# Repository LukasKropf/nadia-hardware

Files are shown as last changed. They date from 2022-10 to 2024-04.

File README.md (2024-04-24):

# NADIA - Hardware

- 3 galvanisch getrennte RS-232 Schnittstellen, [MAX33250EELC+](https://media.digikey.com/pdf/Data%20Sheets/Maxim%20PDFs/MAX33250E_51E_Rev1_Nov2018.pdf)
- 5 digitale Eingänge
- 5 analoge Eingänge
- 3 galvanisch getrennte Ausgänge (Solid State Relais, [G3VM-61GR2](https://omronfs.omron.com/en_US/ecb/products/pdf/en-g3vm_41gr8_61gr.pdf))
- Galvanisch getrennte PoE Speisung

## Übersicht

``` mermaid
flowchart LR
    A[M12 Ethernet mit PoE] --- B[NADIA]
    B --- C[5 Digitale Eingänge]
    B --- D[5 Analoge Eingänge]
    B --- E[3 RS-232 Schnittstellen]
    B --- F[3 Digitale Ausgänge]    
    G[Optionale Speisung] -.- B
    H[micro-USB] -.- B
    I[micro-SD Karte] --- B
    
```
|NADIA im Gehäuse | NADIA PCB |
|-|-|
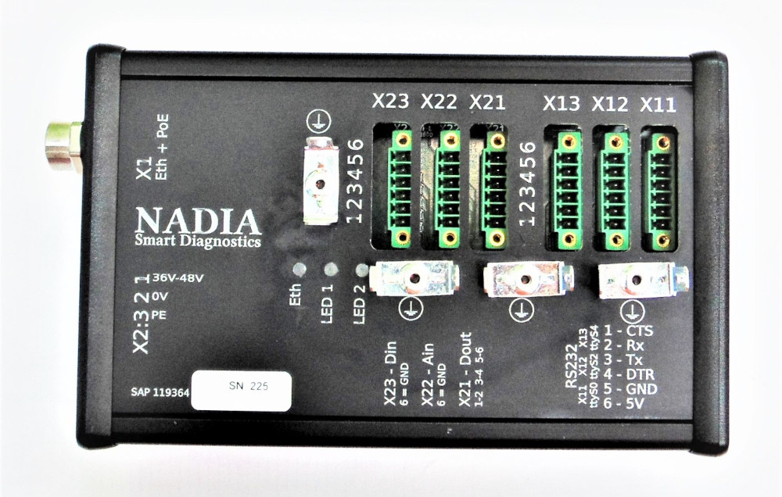
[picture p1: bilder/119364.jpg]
NADIA Foto
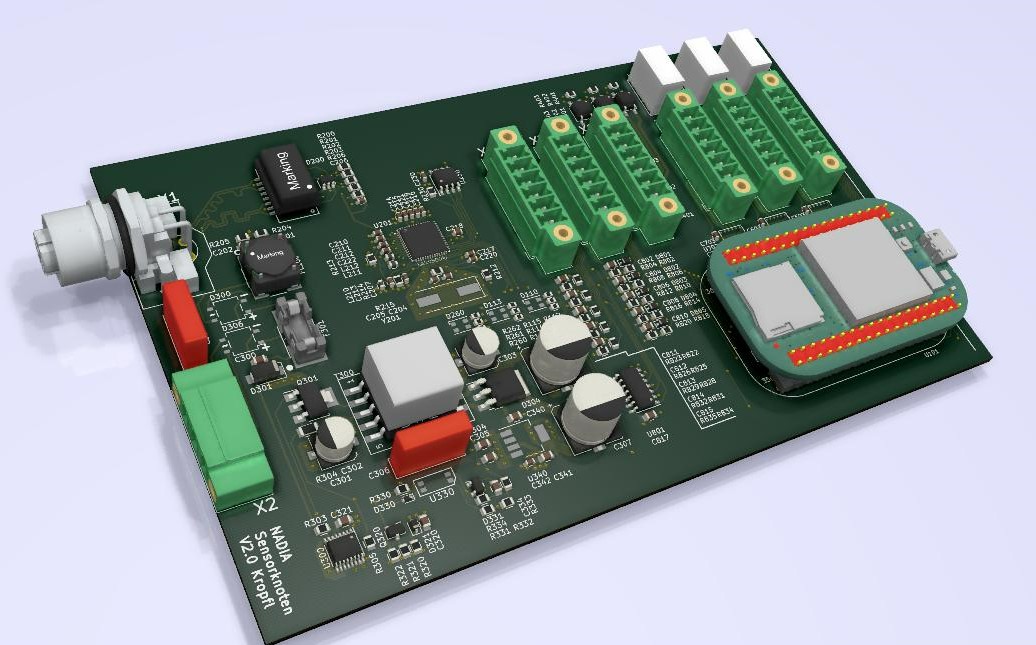
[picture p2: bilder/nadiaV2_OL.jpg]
NADIA PCB
|  ||

## Rechnerplatine

| Wert | Wert | Einheit |
|:---|---|---|
| Rechnerplatine  [Pocketbeagle](https://beagleboard.org/pocket) |  | - |
| RAM |  512 | MB,  DDR3 RAM|
| CPU  [Octavo Systems OSD3358-SM](http://octavosystems.com/octavo_products/osd335x-sm/) |  1 | GHz |
| Speicher |  - | microSD |

## Elektrische Charakteristik

| Wert | Min  | Typisch  | Max | Einheit |
|:---|---|:---:|---|---|
| Speisung Spannung | 36 | 48 | 56 | VDC |
| Speisung Strom | | 50 | 100 | mA |
| Galvanische Trennung Speisung | | | 1.5 | kV |
| **Digitaler Eingang** |
| Schmitt-Trigger [74HC7014D](https://www.mouser.ch/datasheet/2/916/74HC7014-1598223.pdf) |
| Digitaler Eingang Pegel High | | 4 | | VDC |
| Digitaler Eingang Pegel Low | | 3.8 | | VDC |
| Digitaler Eingang maximale Spannung | -100 | | 100 | VDC |
| Digitaler Eingang Eingangswiderstand | 560  | | 660 | kΩ |
| **Analoger Eingang** |
| Spannungsteiler mit Widerständen|
| Analoger Eingang maximale Spannung | -100 | | 100 | VDC |
| Analoger Eingang Messbereich / V | 0 | | 50 | VDC |
| Analoger Eingang Eingangswiderstand | 560  | | 850 | kΩ |
| Analoger Eingang Bandbreite -3dB | | 300 | | Hz |
| **Digitaler Ausgang** |
| Solid State Relais [G3VM-61GR2](https://omronfs.omron.com/en_US/ecb/products/pdf/en-g3vm_41gr8_61gr.pdf) |
| Digitaler Ausgang Spannung | | | 60 | Vpeak AC/DC |
| Digitaler Ausgang Strom | | | 1.7 | A |
| Digitaler Ausgang Schaltfrequent | | | 10 | Hz |
| Digitaler Ausgang Isolationsspannung | | | 1.5 | kV_rms  |
| **RS-232 Schnittstelle** |
| Treiber  [MAX33250EELC+](https://media.digikey.com/pdf/Data%20Sheets/Maxim%20PDFs/MAX33250E_51E_Rev1_Nov2018.pdf)| ||||
| RS-232 Schnittstelle Galvanische Trennung | | 200 | 600 @ 60s | Vrms |
| RS-232 ESD Schutz | | | ±15 | kV |
| RS-232 Eingangswiderstand | 3 | 5 | 7 | kΩ |
| RS-232 Eingangsspannung | | | ±25 | V |
| RS-232 Ausgangsspannung | | ±5 @ 3kΩ | ±13.2 | V |
| RS-232 Ausgangskurzschlussstrom | | | ±70 | mA |

## Konnektivität

### Ethernet

Die Ethernetverbindung wird NADIA intern über einen USB-Ethernet Wandler sichergestellt, dem [LAN9500A von Microchip](https://www.microchip.com/en-us/product/LAN9500A).

Über Ethernet kann auf alle Dienste von NADIA zugegriffen werden.

### Micro USB

Auf NADA kann über die Micro USB Schnittstelle zugegriffen werden. NADIA erstellt über USB eine virtuelle Ethernet-Verbindung her.
Mehr Details siehe die Dokumentation von Beagleboard Pocketbeagle:

- [Getting Started - Enable a network connection](https://beagleboard.org/getting-started#step2)
- [Pocketbeagle System Reference Manual](https://github.com/beagleboard/pocketbeagle/wiki/System-Reference-Manual#533-usb-20-connector)

Über USB kann auf alle Dienste von NADIA zugegriffen werden.

### Wireless

NADIA verfügt über keine Wireless Kommunikationsmöglichkeiten.

### CAN

NADIA verfügt in dieser Version über **kein** CAN.
Allerdings verfügt das Pocketbeagle über die Möglichkeit zwei CAN Schnittstellen anzubinden. Dies würde ein neues PCB-Layout voraussetzen.

### Serial RS232

Die drei seriellen Schnittstellen sind jeweils galvanisch getrennt von der Speisung. Aus Sicherheitsgründen müssen die Schnittstellen über einen GPIO Pin freigeschaltet werden, bevor sie benutzt werden können.

## Software

Als Basisimage dient das Image von Pocketbeagle:
[AM3358 Debian 10.3 2020-04-06 4GB SD IoT](https://beagleboard.org/latest-images)
Um einen zuverlässigen Betrieb sicherzustellen, ist die Erstellung von verschiedenen Partitionen nötig. Die Systempartition in ReadOnly.

[Node-RED](https://nodered.org/) wird für das eigentliche Programmieren verwendet.
Mit Node-RED können auch sehr einfach ansprechende GUIs erstellt werden.

Auf NADIA, respektive dem PocketBeagle, ist auch jede andere ARMHF Linux Software lauffähig.

Beispiele: (jedoch noch keine Erfahrung)

- [OpenPLC](https://www.openplcproject.com/)
- [4DIAC](https://www.eclipse.org/4diac/)

# Licence

Copyright Lukas Kropf 2022.

This source describes Open Hardware and is licensed under the CERN-OHL-W v2  or later.

You may redistribute and modify this documentation and make products
using it under the terms of the CERN-OHL-W v2 (https:/cern.ch/cern-ohl).

This documentation is distributed WITHOUT ANY EXPRESS OR IMPLIED
WARRANTY, INCLUDING OF MERCHANTABILITY, SATISFACTORY QUALITY
AND FITNESS FOR A PARTICULAR PURPOSE. 
Please see the CERN-OHL-W v2 for applicable conditions.

Source location: https://github.com/LukasKropf/nadia-hardware

As per CERN-OHL-W v2 section 4.1, should You produce hardware based on
these sources, You must maintain the Source Location visible on the
external case of NADIA-Hardware or other product you make using
this documentation.

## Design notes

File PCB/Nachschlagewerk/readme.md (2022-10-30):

# todo:

 [ ] Verlinke alle Designresourcen, die nützlich für die Erstellung waren.
 
 DIese Ressourcen sind nicht zwingend für die Reproduktion von NADIA-Hardware.

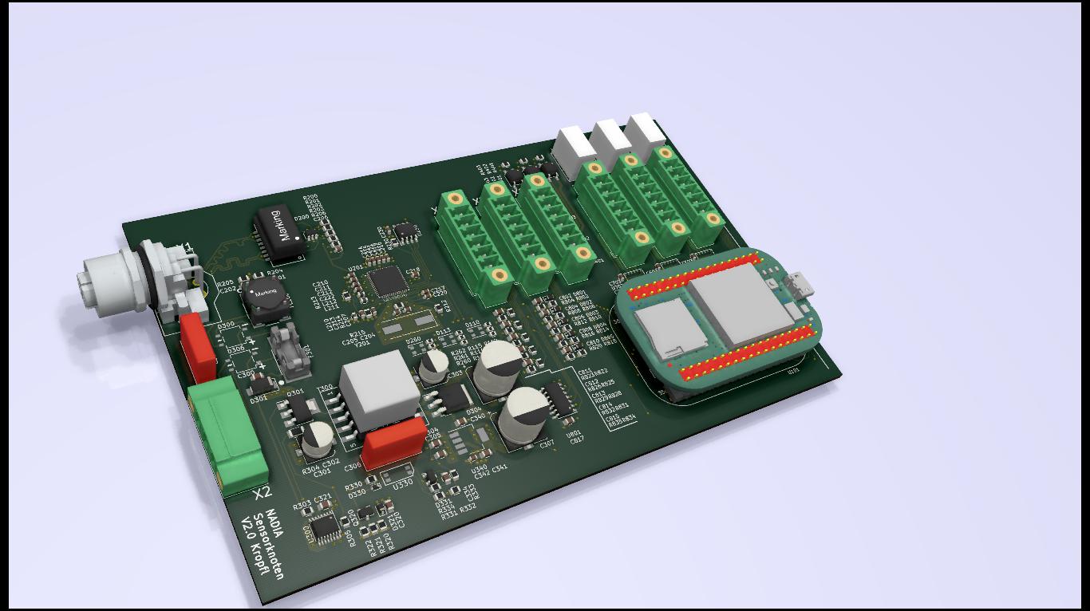
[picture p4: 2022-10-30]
PCB/Bilder/nadiaV2_OL.jpg

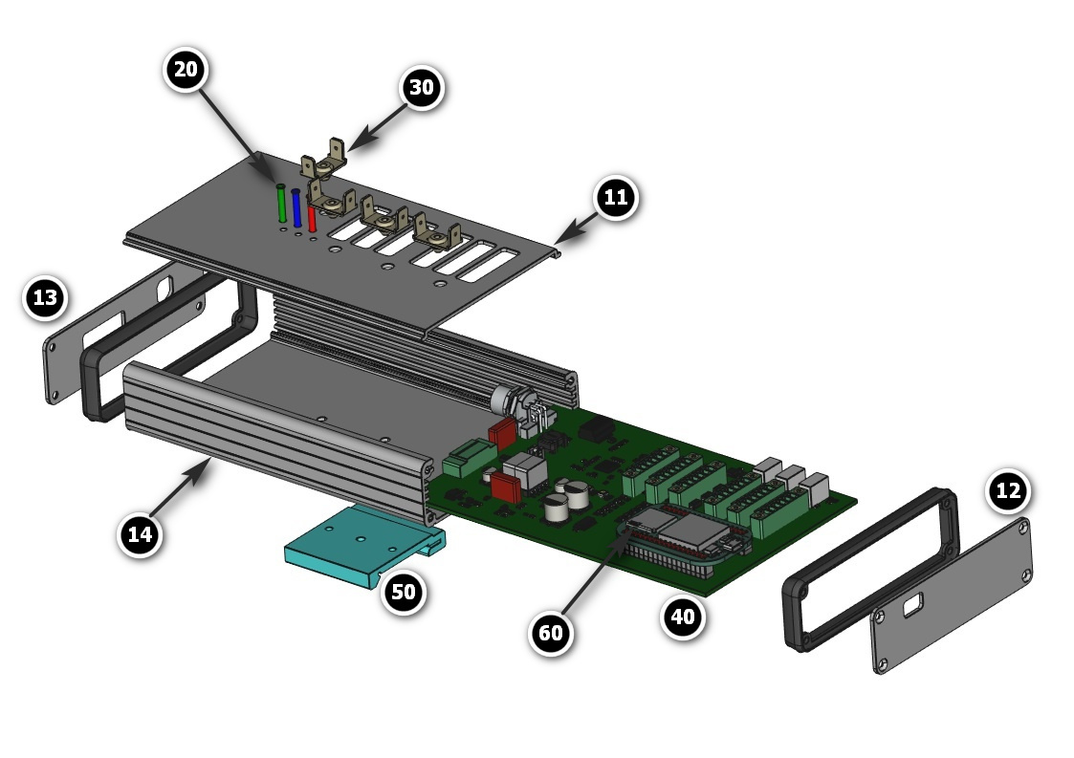
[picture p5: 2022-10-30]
housing/Explosion_weiss_Beschriftet.jpg

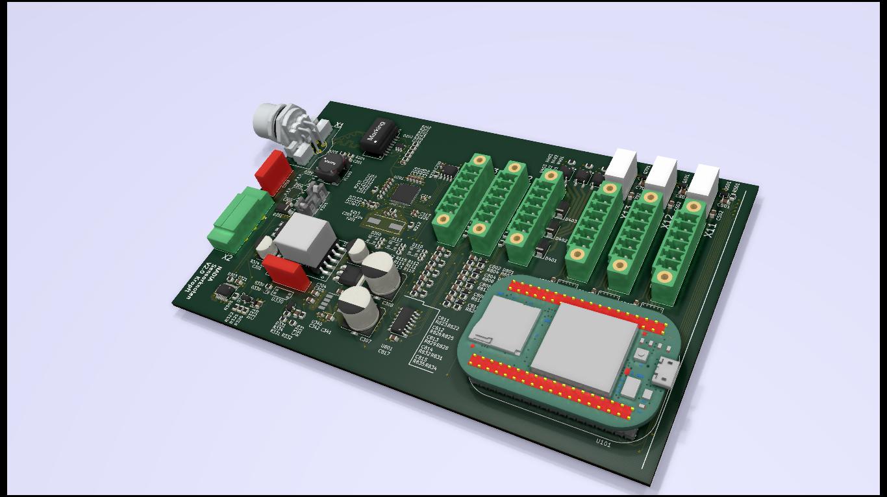
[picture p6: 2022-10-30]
PCB/Bilder/nadiaV2_OR.jpg

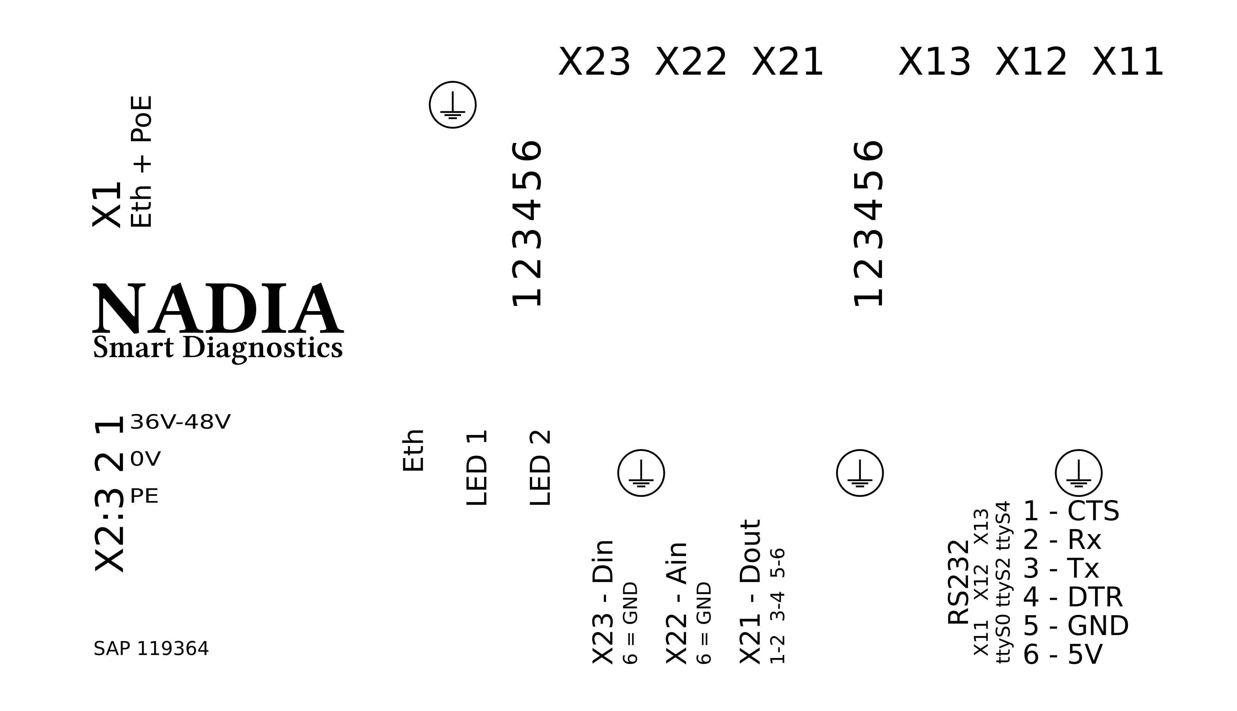
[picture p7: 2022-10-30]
housing/Beschriftung_laser600Deckel.png

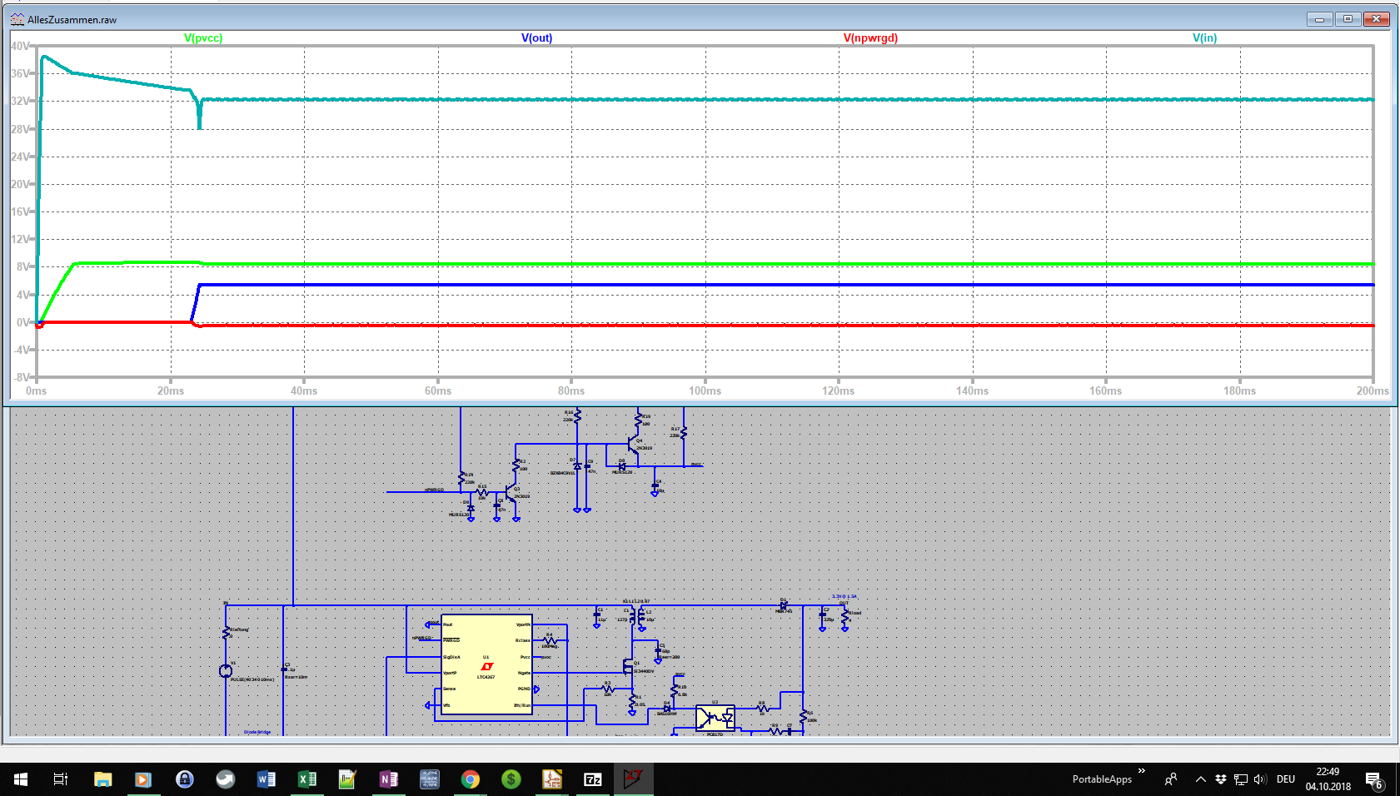
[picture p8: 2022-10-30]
PCB/Simulationen/2018-10-04_224959_LUKAS-PC.png

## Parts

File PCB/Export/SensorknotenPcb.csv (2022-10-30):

Ref | Qty | Value | Footprint | Datasheet | manf | part-num
C201 C202 | 2 | 22n/200V | Capacitors_SMD:C_0805 | https://www.digikey.ch/product-detail/de/avx-corporation/08051C223K4T2A/478-9378-1-ND/4901452 | AVX Corporation | 08052C223KAT2A
C203 C306 | 2 | 1n/2kV | Capacitors_ThroughHole:C_Rect_L13.0mm_W4.0mm_P10.00mm_FKS3_FKP3_MKS4 | https://www.digikey.ch/product-detail/de/wima/MKS4U011003C00KSSD/1928-1762-ND/9370670 | WIMA | MKS4U011003C00KSSD
C204 C205 | 2 | 33pF 50V | Capacitors_SMD:C_0603 | https://www.digikey.ch/product-detail/de/samsung-electro-mechanics/CL10C330FB8NNNC/1276-2262-1-ND/3890348 | Samsung Electro-Mechanics | CL10C330FB8NNNC
C206 C207 C210 C211 C212 C213 C214 C215 C216 C217 C218 C219 C220 C221 C222 C230 C342 C503 C504 C603 C604 C703 C704 | 23 | 0.1µF | Capacitors_SMD:C_0603 | ~ | Samsung Electro-Mechanics | CL10B104KO8NNNC
C300 | 1 | 0.1µF 100V | Capacitors_SMD:C_0805 | https://www.digikey.ch/product-detail/de/tdk-corporation/CGA4J2X7R2A104K125AA/445-5827-1-ND/2443867 | TDK Corporation | CGA4J2X7R2A104K125AA
C301 | 1 | 10µF 63V | Capacitors_SMD:CP_Elec_6.3x5.8 | https://www.digikey.ch/product-detail/de/nichicon/GYA1J100MCQ1GS/493-16371-1-ND/7427999 | Nichicon | GYA1J100MCQ1GS
C302 | 1 | 1µF | Capacitors_SMD:C_0805 | https://www.digikey.ch/product-detail/de/tdk-corporation/CGA4J3X7S2A105M125AE/445-7961-1-ND/2782529 | TDK Corporation | CGA4J3X7S2A105M125AE
C303 | 1 | 330µF | Capacitors_SMD:CP_Elec_6.3x5.8 | https://www.digikey.ch/product-detail/de/wurth-electronics-inc/875105245015/732-6415-1-ND/5147966 | Wurth Electronics Inc. | 875105245015
C304 C305 C321 C340 C341 C502 C602 C702 C817 | 9 | 10µF | Capacitors_SMD:C_0805 | ~ | Samsung Electro-Mechannics | CL21B106KOQNNNE
C307 C308 | 2 | 1500µF | CP_Elec_10x10 | https://www.digikey.ch/product-detail/de/nichicon/UCD0J152MNL1GS/493-6342-1-ND/3438856 | Nichicon | UCD0J152MNL1GS
C320 C802 C804 C806 C808 C810 C811 C812 C813 C814 C815 | 11 | 47nF | Capacitors_SMD:C_0805 | https://www.digikey.ch/product-detail/de/wurth-electronics-inc/885012207070/732-8059-1-ND/5454686 | Wurth Electronics Inc. | 885012207070
C334 | 1 | 6.8nF | Capacitors_SMD:C_0805 | https://www.digikey.ch/product-detail/de/wurth-electronics-inc/885012207121/732-12095-1-ND/9346115 | Wurth Electronics Inc. | 885012207121
C501 C601 C701 | 3 | 10µF | Capacitors_SMD:C_0805 | https://www.digikey.ch/product-detail/de/samsung-electro-mechanics/CL21B106KOQNNNE/1276-2872-1-ND/3890958 | Samsung Electro-Mechannics | CL21B106KOQNNNE
D110 D113 D260 | 3 | LED_ARGB | LEDs:LED_Cree-PLCC4_3.2x2.8mm_CCW | https://www.digikey.ch/product-detail/de/cree-inc/CLV1L-FKB-CHMMQEHBB7673673/CLV1L-FKB-CHMMQEHBB7673673CT-ND/7648419 | Cree Inc. | CLV1L-FKB-CHMMQEHBB7673673
D200 | 1 | WE-TVS_5V | TO_SOT_Packages_SMD:SOT-23-6 |  | Wurth Electronics | 824015
D300 D306 | 2 | D_Bridge_+-AA | Diodes_SMD:Diode_Bridge_TO-269AA | https://www.digikey.ch/product-detail/de/micro-commercial-co/MB110S-TP/MB110S-TPMSCT-ND/2075340 | Micro Commercial Co | MB110S-TP
D301 | 1 | TVS 58V | Diodes_SMD:D_SMA | https://www.digikey.ch/product-detail/de/diodes-incorporated/SMAJ58A-13-F/SMAJ58A-13-FDICT-ND/2242795 | Diodes Incorporated | SMAJ58A-13-F
D304 | 1 | D_Schottky | TO_SOT_Packages_SMD:TO-252-3_TabPin2 | https://www.digikey.ch/product-detail/de/stmicroelectronics/STPS1045B-TR/497-6572-1-ND/1865318 | STMicroelectronics | STPS1045B-TR
D321 | 1 | 9.1V | Diodes_SMD:D_SOD-323 | https://www.digikey.com/product-detail/en/on-semiconductor/MM3Z9V1ST1G/MM3Z9V1ST1GOSCT-ND/5213279 | ON Semiconductor | MM3Z9V1ST1G
D330 | 1 | Fast Recovery | Diodes_SMD:D_SOD-523 | https://www.digikey.com/product-detail/en/micro-commercial-co/BAS516-TP/BAS516-TPMSCT-ND/7681649 | Micro Commercial Co | BAS516-TP
D331 | 1 | TLV431BCDBZR | TO_SOT_Packages_SMD:SOT-23 | http://www.ti.com/lit/ds/symlink/tlv431a.pdf | Texas Instruments | TLV431BCDBZR
D401 D402 D403 | 3 | TVS_45V | Diodes_SMD:D_SMA | https://www.digikey.ch/product-detail/de/vishay-semiconductor-diodes-division/SMAJ45CA-E3-61/SMAJ45CA-E3-61GICT-ND/5639153 | Vishay | SMAJ45CA-E3/61
D801 D802 D803 D804 D805 | 5 | 24V | Diodes_SMD:D_SOD-323F | https://www.digikey.ch/product-detail/de/nexperia-usa-inc/BZX84J-B24115/1727-2134-1-ND/5221782 | Nexperia USA | BZX84J-B24-115
F301 | 1 | 0.35A | EigeneFootprints:FuseHolder_Schurter_0031.7701.11 | https://www.digikey.ch/product-detail/de/schurter-inc/0031.7701.11/486-1991-ND/640027 | Schurter Inc. | 0031.7701.11 | 3404.0043.11
FL100 | 1 | EMI_Filter_Common_WE | EigeneFootprints:CommonModeChoke_WuerthType-WE-SL5 | https://www.digikey.ch/de/ptm/w/wurth-electronics-inc/suppression-of-common-mode-noise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 | WE | 744272392
L210 L211 L212 | 3 | Ferrite_Bead | Inductors_SMD:L_0603 | https://www.digikey.ch/product-detail/de/murata-electronics-north-america/BLM18PG121SN1D/490-1037-1-ND/584485 | Murata | BLM18PG121SN1D
Q301 | 1 | Q_NMOS_GDSD | TO_SOT_Packages_SMD:SOT-223 | https://www.fairchildsemi.com/datasheets/FD/FDT86246L.pdf | On Semiconductor | FDT86246L
Q320 | 1 | Q_NPN_BEC | TO_SOT_Packages_SMD:SOT-23 | https://www.digikey.com/product-detail/en/diodes-incorporated/FMMT493TA/FMMT493CT-ND/92663 | Diodes Incorporated | FMMT493TA
Q501 Q601 Q701 | 3 | DMG1012UW-7 | TO_SOT_Packages_SMD:SOT-323_SC-70 | https://www.digikey.ch/product-detail/de/diodes-incorporated/DMG1012UW-7/DMG1012UW-7DICT-ND/2183242 | Diodes Incorporated | DMG1012UW-7
R110 R113 R260 | 3 | 240 | Resistors_SMD:R_0603 | https://www.digikey.ch/product-detail/de/panasonic-electronic-components/ERJ-3GEYJ241V/P240GCT-ND/134760 | Panasonic Electronic Components | ERJ-3GEYJ241V
R111 R114 R261 | 3 | 62 | Resistors_SMD:R_0603 | https://www.digikey.ch/product-detail/de/panasonic-electronic-components/ERJ-3GEYJ620V/P62GCT-ND/134695 | Panasonic Electronic Components | ERJ-3GEYJ620V
R112 R115 R262 | 3 | 62 | Resistors_SMD:R_0603 | https://www.digikey.ch/product-detail/de/panasonic-electronic-components/ERJ-3GEYJ241V/P240GCT-ND/134760 | Panasonic Electronic Components | ERJ-3GEYJ620V
R200 R201 R202 R203 | 4 | 49.9 1% | Resistors_SMD:R_0805 | ~ | Panasonic Electronic Componens | ERJ-6ENF49R9V
R204 R205 | 2 | 75 | Resistors_SMD:R_0805 | ~ | Panasonic Electronic Componens | ERJ-6ENF75R0V
R206 R212 R251 R252 R253 R800 | 6 | 0R | Resistors_SMD:R_0805 | ~ | Panasonic Electronic Componens | ERJ-6GEY0R00V
R213 R214 | 2 | 12k 1% | Resistors_SMD:R_0805 | ~ | Panasonic Electronic Componens | ERJ-6ENF1202V
R215 R303 | 2 | open | Resistors_SMD:R_0805 | ~ | DNP | DNP
R230 R305 R334 | 3 | 10k | Resistors_SMD:R_0805 | ~ | Panasonic Electronic Componens | ERJ-6ENF1002V
R304 | 1 | 0.05 1% | Resistors_SMD:R_1206 | https://www.digikey.ch/product-detail/de/stackpole-electronics-inc/CSNL1206FT50L0/CSNL1206FT50L0CT-ND/5226376 | Stackpole Electronics Inc. | CSNL1206FT50L0
R320 R322 | 2 | 220k | Resistors_SMD:R_0805 | ~ | Panasonic Electronic Componens | ERJ-6ENF2203V
R321 | 1 | 100 | Resistors_SMD:R_0805 | ~ | Panasonic Electronic Componens | ERJ-6ENF1000V
R330 | 1 | 6k8 | Resistors_SMD:R_0805 | ~ | Panasonic Electronic Componens | ERJ-6ENF6801V
R331 R822 R825 R828 R831 R834 | 6 | 1k | Resistors_SMD:R_0805 | ~ | Panasonic Electronic Componens | ERJ-6ENF1001V
R332 R501 R601 R701 | 4 | 100k | Resistors_SMD:R_0805 | https://www.digikey.ch/product-detail/de/panasonic-electronic-components/ERA-6AEB104V/P100KDACT-ND/1465995 | Panasonic Electronic Componens | ERJ-6ENF1003V
R333 | 1 | 33k | Resistors_SMD:R_0805 | ~ | Panasonic Electronic Componens | ERJ-6ENF3302V
R401 R402 R403 | 3 | 200 | Resistors_SMD:R_0805 | ~ | Panasonic Electronic Components | ERJ-6ENF2000V
R801 R802 R805 R806 R809 R810 R813 R814 R817 R818 R821 R823 R824 R826 R827 R829 R830 R832 R833 R835 | 20 | 560k | Resistors_SMD:R_0805 | ~ | Yageo | RC0805JR-07560KL
R804 R808 R812 R816 R820 | 5 | 43k | Resistors_SMD:R_0805 | ~ | Yageo | RC0805FR-0743KL
T200 | 1 | 749013011A | EigeneFootprints:WE-LAN_PoE_749013011A | http://katalog.we-online.de/pbs/datasheet/749013011A.pdf | Wurth Electrionik | 749013011A
T300 | 1 | WE_750310013 | EigeneFootprints:WE_EP13 | http://katalog.we-online.de/pbs/datasheet/750310013.pdf | Wurth Electrionik | 750310013
TP301 | 1 | R304_Shunt | Measurement_Points:Measurement_Point_Round-SMD-Pad_Small | ~ | DNP | DNP
TP320 | 1 | TP_Pvcc | Measurement_Points:Measurement_Point_Round-SMD-Pad_Small | ~ | DNP | DNP
TP330 | 1 | TP_U300_run | Measurement_Points:Measurement_Point_Round-SMD-Pad_Small | ~ | DNP | DNP
TP331 | 1 | TP_Opto5V | Measurement_Points:Measurement_Point_Round-SMD-Pad_Small | ~ | DNP | DNP
TP340 | 1 | TP_3.3V | Measurement_Points:Measurement_Point_Round-SMD-Pad_Small | ~ | DNP | DNP
TP341 | 1 | TP_5V | Measurement_Points:Measurement_Point_Round-SMD-Pad_Small | ~ | DNP | DNP
U101 | 1 | PocketBeagle | EigeneFootprints:PocketBeagle | https://github.com/beagleboard/pocketbeagle/wiki/System-Reference-Manual | GHI Electronics LLC | POCKETBEAGLE-SC-569
U101 | 2 |  |  |  | samtec | SLW-118-01-G-D
U101 | 2 |  |  |  | samtec | TSW-118-05-G-D
U201 | 1 | LAN9500Ai | EigeneFootprints:QFN50P800X800X120-56N | http://ww1.microchip.com/downloads/en/DeviceDoc/00001875C.pdf | Microchip Technology | LAN9500A-ABZJ-TR
U230 | 1 | 93AA56A | Housings_SOIC:SOIC-8_3.9x4.9mm_Pitch1.27mm | https://www.digikey.ch/product-detail/de/microchip-technology/93AA56AT-I-SN/93AA56AT-I-SNCT-ND/8637200 | Microchip Technology | 93AA56AT-I/SN
U300 | 1 | LTC4267 | Housings_SSOP:SSOP-16_3.9x4.9mm_Pitch0.635mm | https://www.digikey.ch/product-detail/de/linear-technology-analog-devices/LTC4267CGN-TRPBF/LTC4267CGN-TRPBFCT-ND/8019541 | Linear Technology/Analog Devices | LTC4267CGN#TRPBF
U330 | 1 | PS2911 | EigeneFootprints:DIP-4_SMD_Opto | https://www.digikey.ch/products/de?keywords=PS2911-1-M-AX | CEL | PS2911-1-M-AX
U340 | 1 | LP38693MP-3.3 | TO_SOT_Packages_SMD:SOT-223-5 |  | Texas Instruments | LP38693MP-3.3/NOPB
U401 U402 U403 | 3 | G3VM-61VR(TR05) | EigeneFootprints:SOP-4_3.9x4.4mm_Pitch2.54mm | https://www.digikey.ch/product-detail/de/omron-electronics-inc-emc-div/G3VM-61VR-TR05/Z10319CT-ND/8602730 | Omron Electronics Inc-EMC Div | G3VM-61VR(TR05)
U501 U601 U701 | 3 | RFM-0505S | EigeneFootprints:RFM-xxxxS | https://www.digikey.ch/product-detail/de/recom-power/RFM-0505S/945-3159-ND/8550767 | Recom Power | RFM-0505S
U502 U602 U702 | 3 | MAX33250E_51E | EigeneFootprints:LGA-12 | https://media.digikey.com/pdf/Data%20Sheets/Maxim%20PDFs/MAX33250E_51E_Rev1_Nov2018.pdf | Maxim Integrated | MAX33250EELC+
U801 | 1 | 74HC7014D-118 | Housings_SOIC:SOIC-14_3.9x8.7mm_Pitch1.27mm | https://assets.nexperia.com/documents/data-sheet/74HC7014.pdf | Nexperia USA inc. | 74HC7014D-118
X1 | 1 | Phoenix_1436550 | EigeneFootprints:Phoenix_SACC-DSIV-M12FSD-4CON-L90 | https://www.digikey.ch/product-detail/de/phoenix-contact/1436550/277-16526-ND/3607351 | Phoenix Conact | 1436550
X2 | 1 | Phoenix_1847479 | Connectors_Phoenix:PhoenixContact_MC-GF_03x5.08mm_Angled_ThreadedFlange | https://www.digikey.ch/product-detail/de/phoenix-contact/1847479/277-7461-ND/3596799 | PhoenixContact | 1847479
X11 X12 X13 | 3 | Phoenix_1843266 | Connectors_Phoenix:PhoenixContact_MCV-GF_06x3.50mm_Vertical_ThreadedFlange_MountHole | ~ | Phoenix Contact | 1843266
X21 | 1 | Phoenix_1843266 | Connectors_Phoenix:PhoenixContact_MCV-GF_06x3.50mm_Vertical_ThreadedFlange_MountHole | https://www.digikey.ch/product-detail/de/phoenix-contact/1843813/277-6088-ND/2527947 | Phoenix Contact | 1843266
X22 | 1 | Phoenix_1843266 | Connectors_Phoenix:PhoenixContact_MCV-GF_06x3.50mm_Vertical_ThreadedFlange_MountHole |  | Phoenix Contact | 1843266
X23 | 1 | Phoenix_1843266 | Connectors_Phoenix:PhoenixContact_MCV-GF_06x3.50mm_Vertical_ThreadedFlange_MountHole | https://www.digikey.ch/products/de?keywords=1843855 | Phoenix Contact | 1843266
Y201 | 1 | 25.000MHz 18pF | Crystals:Crystal_SMD_HC49-SD | https://www.digikey.ch/product-detail/de/abracon-llc/ABLS2-25.000MHZ-D4YF-T/535-9883-1-ND/2001506 | Abracon LLC | ABLS2-25.000MHZ-D4YF-T

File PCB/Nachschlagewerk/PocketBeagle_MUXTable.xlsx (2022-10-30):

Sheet: P1
Header.Pin | Silkscreen | PocketBeagle wiring | Proc Ball | SiP Ball | Mode0 (Name) | Mode1 | Mode2 | Mode3 | Mode4 | Mode5 | Mode6 | Mode7
P1.01 | VIN | P1.01 (VIN) |  | P10 & R10 & T10 | VIN
P1.02 | A6/87 | P1.02 (AIN6/GPIO87) | A8 | C9 | ain6
P1.02 | A6/87 | P1.02 (AIN6/GPIO87) | R5 | F2 | lcd_hsync | gpmc_a9 | gpmc_a2 | pr1_edio_data_in3 | pr1_edio_data_out3 | pr1_pru1_pru_r30_9 | pr1_pru1_pru_r31_9 | gpio2_23
P1.03 | USB1_EN | P1.03 (USB1-DRVVBUS) | F15 | M14 | USB1_DRVVBUS | - | - | - | - | - | - | gpio3_13
P1.04 | 89 | P1.04 (PRU1.11) | R6 | E1 | lcd_ac_bias_en | gpmc_a11 | pr1_mii1_crs | pr1_edio_data_in5 | pr1_edio_data_out5 | pr1_pru1_pru_r30_11 | pr1_pru1_pru_r31_11 | gpio2_25
P1.05 | USB1_VB | P1.05 (USB1-VBUS) | T18 | M15 | USB1_VBUS | - | - | - | - | - | - | -
P1.06 | SPI0_CS | P1.06 (SPI0-CS) | A16 | A14 | spi0_cs0 | mmc2_sdwp | I2C1_SCL | ehrpwm0_synci | pr1_uart0_txd | pr1_edio_data_in1 | pr1_edio_data_out1 | gpio0_5
P1.07 | USB1_VI | P1.07 (VIN-USB) |  | P9 &R9 &T9 | VIN-USB
P1.08 | SPI0_CLK | P1.08 (SPI0-CLK) | A17 | A13 | spi0_sclk | uart2_rxd | I2C2_SDA | ehrpwm0A | pr1_uart0_cts_n | pr1_edio_sof | EMU2 | gpio0_02
P1.09 | USB1 - | P1.09 (USB1-DN) | R18 | L16 | USB1_DM | - | - | - | - | - | - | -
P1.10 | SPI0_MISO | P1.10 (SPI0-MISO) | B17 | B13 | spi0_d0 | uart2_txd | I2C2_SCL | ehrpwm0B | pr1_uart0_rts_n | pr1_edio_latch_in | EMU3 | gpio0_3
P1.11 | USB1 + | P1.11 (USB1-DP) | R17 | L15 | USB1_DP | - | - | - | - | - | - | -
P1.12 | SPI0_MOSI | P1.12 (SPI0-MOSI) | B16 | B14 | spi0_d1 | mmc1_sdwp | I2C1_SDA | ehrpwm0_tripzone_input | pr1_uart0_rxd | pr1_edio_data_in0 | pr1_edio_data_out0 | gpio0_04
P1.13 | USB1_ID | P1.13 (USB1-ID) | P17 | L14 | USB1_ID | - | - | - | - | - | - | -
P1.14 | +3.3V | P1.14 (VOUT-3.3V) |  | F6 & F7 & G6 & G7 | VOUT-3.3V
P1.15 | USB1_GND | P1.15 (GND) |  |  | GND
P1.16 | GND | P1.16 (GND) |  |  | GND
P1.17 | AIN(1.8V)- | P1.17 (VREFN) | A9 | B9 | VREFN
P1.18 | AIN(1.8V)A+ | P1.18 (VREFP) | B9 | B7 | VREFP
P1.19 | AIN(1.8V)0 | P1.19 (AIN0-1.8V) | B6 | A8 | ain0
P1.20 | 20 | P1.20 (PRU0.16) | D14 | B4 | xdma_event_intr1 | - | tclkin | clkout2 | timer7 | pr1_pru0_pru_r31_16 | EMU3 | gpio0_20
P1.21 | AIN(1.8V)1 | P1.21 (AIN1-1.8V) | C7 | B8 | ain1
P1.22 | GND | P1.22 (GND) |  |  | GND
P1.23 | AIN(1.8V)2 | P1.23 (AIN2-1.8V) | B7 | B6 | ain2
P1.24 | VOUT | P1.24 (VOUT-5V) |  | K6 & K7 & L6 & L7 | VOUT-5V
P1.25 | AIN(1.8V)3 | P1.25 (AIN3-1.8V) | A7 | C6 | ain3
P1.26 | I2C2_SDA | P1.26 (I2C2-SDA) | D18 | B10 | uart1_ctsn | timer6 | dcan0_tx | I2C2_SDA | spi1_cs0 | pr1_uart0_cts_n | pr1_edc_latch0_in | gpio0_12
P1.27 | AIN(1.8V)4 | P1.27 (AIN4-1.8V) | C8 | C7 | ain4
P1.28 | I2C2_SCL | P1.28 (I2C2-SCL) | D17 | A10 | uart1_rtsn | timer5 | dcan0_rx | I2C2_SCL | spi1_cs1 | pr1_uart0_rts_n | pr1_edc_latch1_in | gpio0_13
P1.29 | PRU0_7 | P1.29 (PRU0.7) | A14 | C4 | mcasp0_ahclkx | eQEP0_strobe | mcasp0_axr3 | mcasp1_axr1 | EMU4 | pr1_pru0_pru_r30_7 | pr1_pru0_pru_r31_7 | gpio3_21
P1.30 | U0_TX | P1.30 (UART0-TX) | E16 | B12 | uart0_txd | spi1_cs1 | dcan0_rx | I2C2_SCL | eCAP1_in_PWM1_out | pr1_pru1_pru_r30_15 | pr1_pru1_pru_r31_15 | gpio1_11
P1.31 | PRU0_4 | P1.31 (PRU0.4) | B12 | A3 | mcasp0_aclkr | eQEP0A_in | mcasp0_axr2 | mcasp1_aclkx | mmc0_sdwp | pr1_pru0_pru_r30_4 | pr1_pru0_pru_r31_4 | gpio3_18
P1.32 | U0_RX | P1.32 (UART0-RX) | E15 | A12 | uart0_rxd | spi1_cs0 | dcan0_tx | I2C2_SDA | eCAP2_in_PWM2_out | pr1_pru1_pru_r30_14 | pr1_pru1_pru_r31_14 | gpio1_10
P1.33 | PRU0_1 | P1.33 (PRU0.1) | B13 | A2 | mcasp0_fsx | ehrpwm0B | - | spi1_d0 | mmc1_sdcd | pr1_pru0_pru_r30_1 | pr1_pru0_pru_r31_1 | gpio3_15
P1.34 | 26 | P1.34 (GPIO0.26) | T11 | R5 | gpmc_ad10 | lcd_data21 | mmc1_dat2 | mmc2_dat6 | ehrpwm2_tripzone_input | pr1_mii0_txen | - | gpio0_26
P1.35 | P1.10 | P1.35 (PRU1.10) | V5 | F1 | lcd_pclk | gpmc_a10 | pru_mii0_crs | pr1_edio_data_in4 | pr1_edio_data_out4 | pr1_pru1_pru_r30_10 | pr1_pru1_pru_r31_10 | gpio2_24
P1.36 | PWM0A | P1.36 (PWM0A) | A13 | A1 | mcasp0_aclkx | ehrpwm0A | - | spi1_sclk | mmc0_sdcd | pr1_pru0_pru_r30_0 | pr1_pru0_pru_r31_0 | gpio3_14

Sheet: P2
Header.Pin | Silkscreen | PocketBeagle wiring | Proc Ball | SiP Ball | Mode0 (Name) | Mode1 | Mode2 | Mode3 | Mode4 | Mode5 | Mode6 | Mode7
P2.01 | PWM1A | P2.01 (PWM1A) | U14 | P12 | gpmc_a2 | gmii2_txd3 | rgmii2_td3 | mmc2_dat1 | gpmc_a18 | pr1_mii1_txd2 | ehrpwm1A | gpio1_18
P2.02 | 59 | P2.02 (GPIO1.27) | V17 | T16 | gpmc_a11 | gmii2_rxd0 | rgmii2_rd0 | rmii2_rxd0 | gpmc_a27 | pr1_mii1_rxer | mcasp0_axr1 | gpio1_27
P2.03 | 23 | P2.03 (GPIO0.23) | T10 | P5 | gpmc_d9 | lcd_data22 | mmc1_dat1 | mmc2_dat5 | ehrpwm2B | pr1_mii0_col | - | gpio0_23
P2.04 | 58 | P2.04 (GPIO1.26) | T16 | R15 | gpmc_a10 | gmii2_rxd1 | rgmii2_rd1 | rmii2_rxd1 | gpmc_a26 | pr1_mii1_rxdv | mcasp0_axr0 | gpio1_26
P2.05 | U1_RX | P2.05 (UART4-RX) | T17 | P15 | gpmc_wait0 | gmii2_crs | gpmc_csn4 | rmii2_crs_dv | mmc1_sdcd | pr1_mii1_col | uart4_rxd | gpio0_30
P2.06 | 57 | P2.06 (GPIO1.25) | U16 | T15 | gpmc_a9 | gmii2_rxd2 | rgmii2_rd2 | mmc2_dat7 / rmii2_crs_dv | gpmc_a25 | pr1_mii_mr1_clk | mcasp0_fsx | gpio1_25
P2.07 | U1_TX | P2.07 (UART4-TX) | U17 | R16 | gpm_ wp | gmii2_rxerr | gpmc_csn5 | rmii2_rxerr | mmc2_sdcd | pr1_mii1_txen | uart4_txd | gpio0_31
P2.08 | 60 | P2.08 (GPIO1.28) | U18 | N14 | gpmc_be1n | gmii2_col | gpmc_csn6 | mmc2_dat3 | gpmc_dir | pr1_mii1_rxlink | mcasp0_aclkr | gpio1_28
P2.09 | I2C1_SCL | P2.09 (I2C1-SCL) | D15 | B11 | uart1_txd | mmc2_sdwp | dcan1_rx | I2C1_SCL | - | pr1_uart0_txd | pr1_pru0_pru_r31_16 | gpio0_15
P2.10 | 52 | P2.10 (GPIO1.20) | R14 | R13 | gpmc_a4 | gmii2_txd1 | rgmii2_td1 | rmii2_txd1 | gpmc_a20 | pr1_mii1_txd0 | eQEP1A_in | gpio1_20
P2.11 | I2C1_SDA | P2.11 (I2C1-SDA) | D16 | A11 | uart1_rxd | mmc1_sdwp | dcan1_tx | I2C1_SDA | - | pr1_uart0_rxd | pr1_pru1_pru_r31_16 | gpio0_14
P2.12 | PB | P2.12 (POWER_BTN) |  | T11 | POWER
P2.13 | VOUT | P2.13 (VOUT-5V) |  | K6, K7, L6, L7 | VOUT-5V
P2.14 | BAT + | P2.14 (VIN-BAT) |  | P8, R8, T8 | VIN-BAT
P2.15 | GND | P2.15 (GND) |  |  | GND
P2.16 | BAT - | P2.16 (BAT-TEMP) |  | N6 | BAT-TEMP
P2.17 | 65 | P2.17 (GPIO2.1) | V12 | T7 | gpmc_clk | lcd_memory_clk | gpmc_wait1 | mmc2_clk | pr1_mii1_crs | pr1_mdio_mdclk | mcasp0_fsr | gpio2_01
P2.18 | 47 | P2.18 (PRU0.15i) | U13 | P7 | gpmc_ad15 | lcd_data16 | mmc1_dat7 | mmc2_dat3 | eQEP2_strobe | pr1_ecap0_ecap_capin_apwm_o | pr1_pru0_pru_r31_15 | gpio1_15P
2.19 | 27 | P2.19 (GPIO0.27) | U12 | T5 | gpmc_ad11 | lcd_data20 | mmc1_dat3 | mmc2_dat7 | ehrpwm0_synco | pr1_mii0_txd3 | - | gpio0_27
P2.20 | 64 | P2.20 (GPIO2.0) | T13 | R7 | gpmc_csn3 | gpmc_a3 | rmii2_crs_dv | mmc2_cmd | pr1_mii0_crs | pr1_mdio_data | EMU4 | gpio2_00
P2.21 | GND | P2.21 (GND) |  |  | GND
P2.22 | 46 | P2.22 (GPIO1.14) | V13 | T6 | gpmc_ad14 | lcd_data17 | mmc1_dat6 | mmc2_dat2 | eQEP2_index | pr1_mii0_txd0 | pr1_pru0_pru_r31_14 | gpio1_14
P2.23 | +3.3V | P2.23 (VOUT-3.3V) |  | F6 & F7 & G6 & G7 | VOUT-3.3V
P2.24 | 48 | P2.24 (GPIO1.12) | T12 | P6 | gpmc_ad12 | lcd_data19 | mmc1_dat4 | mmc2_dat0 | eQEP2A_in | pr1_mii0_txd2 | pr1_pru0_pru_r30_14 | gpio1_12
P2.25 | SPI1_MOSI | P2.25 (SPI1-MOSI) | E17 | C13 | uart0_rtsn | uart4_txd | dcan1_rx | I2C1_SCL | spi1_d1 | spi1_cs0 | pr1_edc_sync1_out | gpio1_09
P2.26 | RST | P2.26 (NRESET) | A10 | R11 | nRESETIN_OUT | - | - | - | - | - | - | -
P2.27 | SPI1_MISO | P2.27 (SPI1-MISO) | E18 | C12 | uart0_ctsn | uart4_rxd | dcan1_tx | I2C1_SDA | spi1_d0 | timer7 | pr1_edc_sync0_out | gpio1_08
P2.28 | PRU0_6 | P2.28 (PRU0.6) | D13 | C3 | mcasp0_axr1 | eQEP0_index | - | mcasp1_axr0 | EMU3 | pr1_pru0_pru_r30_6 | pr1_pru0_pru_r31_6 | gpio3_20
P2.29 | SPI1_CLK | P2.29 (SPI1-CLK) | C18 | C5 | eCAP0_in_PWM0_out | uart3_txd | spi1_cs1 | pr1_ecap0_ecap_capin_apwm_o | spi1_sclk | mmc0_sdwp | xdma_event_intr2 | gpio0_7
P2.30 | PRU0_3 | P2.30 (PRU0.3) | C12 | B1 | mcasp0_ahclkr | ehrpwm0_synci | mcasp0_axr2 | spi1_cs0 | eCAP2_in_PWM2_out | pr1_pru0_pru_r30_3 | pr1_pru0_pru_r31_3 | gpio3_17
P2.31 | SPI1_CS | P2.31 (SPI1-CS) | A15 | A4 | xdma_event_intr0 | - | timer4 | clkout1 | spi1_cs1 | pr1_pru1_pru_r31_16 | EMU2 | gpio0_19
P2.32 | PRU0_2 | P2.32 (PRU0.2) | D12 | B2 | mcasp0_axr0 | ehrpwm0_tripzone_input | - | spi1_d1 | mmc2_sdcd | pr1_pru0_pru_r30_2 | pr1_pru0_pru_r31_2 | gpio3_16
P2.33 | 45 | P2.33 (GPIO1.13) | R12 | R6 | gpmc_ad13 | lcd_data18 | mmc1_dat5 | mmc2_dat1 | eQEP2B_in | pr1_mii0_txd1 | pr1_pru0_pru_r30_15 | gpio1_13
P2.34 | PRU0_5 | P2.34 (PRU0.5) | C13 | B3 | mcasp0_fsr | eQEP0B_in | mcasp0_axr3 | mcasp1_fsx | EMU2 | pr1_pru0_pru_r30_5 | pr1_pru0_pru_r31_5 | gpio3_19
P2.35 | A5/86 | P2.35 (AIN5/GPIO86) | B8 | C8 | ain5
P2.35 | A5/86 | P2.35 (AIN5/GPIO86) | U5 | F3 | lcd_vsync | gpmc_a8 | gpmc_a1 | pr1_edio_data_in2 | pr1_edio_data_out2 | pr1_pru1_pru_r30_8 | pr1_pru1_pru_r31_8 | gpio2_22

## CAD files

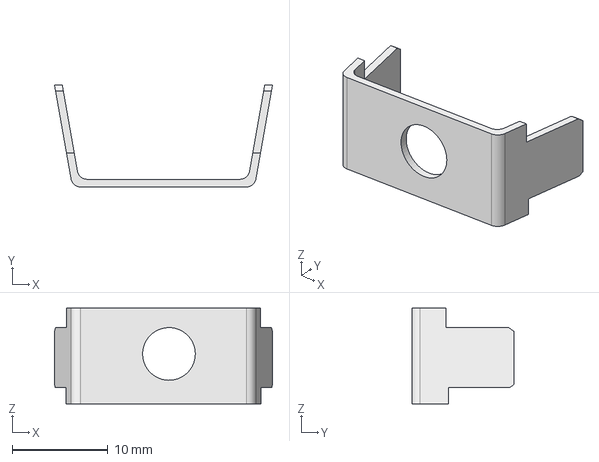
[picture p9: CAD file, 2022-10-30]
housing/RIV236.FCStd
22.7 x 10.6 x 10.0 mm

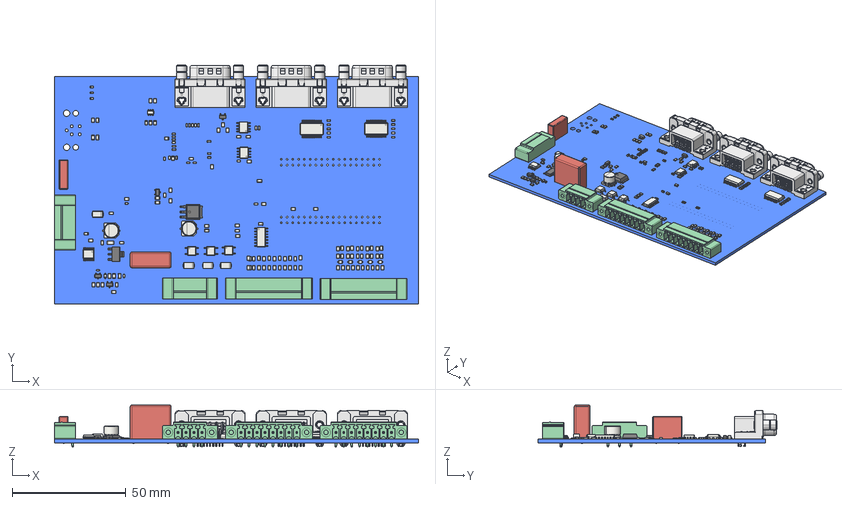
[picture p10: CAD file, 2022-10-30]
PCB/SensorknotenPcb.FCStd
160.0 x 105.2 x 18.4 mm
Pcb
C608_C_0805_5BB779BB
C610_C_0805_5BB7798B
C612_C_0805_5BB7795B
C614_C_0805_5BB7792B
C616_C_0805_5BB778FB
C340_C_0805_5BB29A94
C502_C_0603_5BB6DB34
C503_C_0805_5BB6D693
D304_TO_252_3_TabPin2_5BB8906A
D501_SOT_23_5BB3DA40
U601_SOIC-14_3.9x8.7mm_Pitch1.27mm_5BB3103E
U501_SOIC-8_3.9x4.9mm_Pitch1.27mm_5BB3F8C0
D200_SOT_23_6_5BB5BC0F
C201_C_0805_5BB587D8
C202_C_0805_5BB2988F
C203_C_Rect_L130mm_W40mm_P1000mm_FKS3_FKP3_MKS4_5BB5770D
C205_C_0603_5BB7BF1D
C204_C_0603_5BB298C4
C207_C_0603_5BB3E5B6
C210_C_0603_5BB298E6
C211_C_0603_5BB298F7
C212_C_0603_5BB53E95
C213_C_0603_5BB567D4
C214_C_0603_5BB2992A
C215_C_0603_5BB2993B
C216_C_0603_5BB2994C
C217_C_0603_5BB2995D
C218_C_0603_5BB2996E
C219_C_0603_5BB2997F
C220_C_0603_5BB29990
C221_C_0603_5BB299A1
C222_C_0603_5BB299B2
C230_C_0603_5BB299C3
C300_C_0805_5BB7C4DE
C301_CP_Elec_6.3x5.8_5BB299F0
C302_C_0805_5BB29A01
C303_CP_Elec_6.3x5.8_5BB8900D
C304_C_0805_5BB88FD2
C305_C_0805_5BB88FA2
C310_C_0805_5BB7EFF3
C320_C_0805_5BB7EFC3
C321_C_0805_5BB29A72
C334_C_0805_5BB29A83
C341_C_0805_5BB29AA5
C342_C_0603_5BB29AB6
C401_C_0603_5BB29AC7
C402_C_0603_5BB4E232
C403_C_0603_5BB4BDD0
C404_C_0603_5BB4DA6A
C405_C_0603_5BB7D142
C406_C_0603_5BB29B1C
C407_C_0603_5BB29B2D
C408_C_0603_5BB29B3E
C409_C_0603_5BB7C796
C410_C_0603_5BB29B60
C501_C_0603_5BB7A3F7
C601_C_0805_5BB29B93
C602_C_0805_5BB29BA4
C603_C_0805_5BB29BB5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

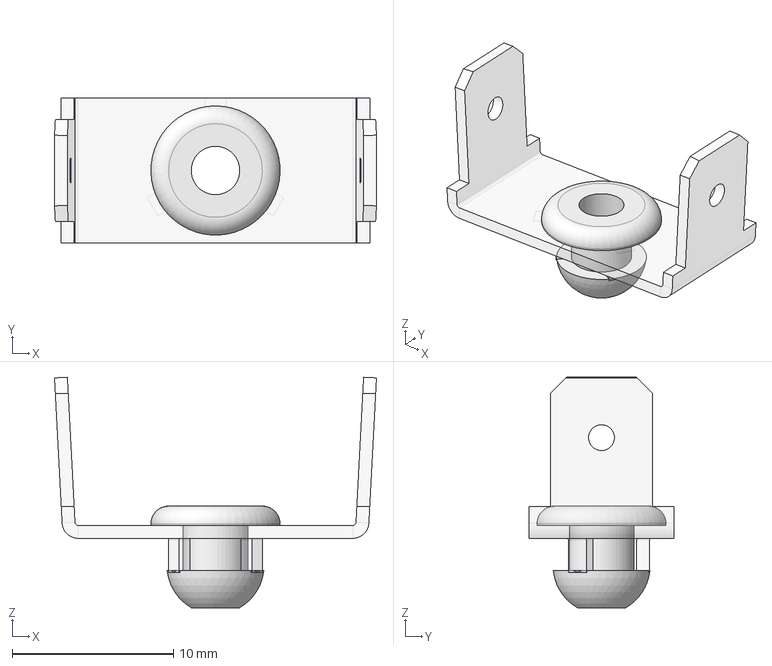
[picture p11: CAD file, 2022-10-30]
housing/RIV236_v2.FCStd
19.9 x 9.00 x 14.3 mm
Niete

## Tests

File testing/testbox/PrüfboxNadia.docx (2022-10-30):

Quantity | Distrelec Article Number | Reference | Manufacturer | Manufacturer Article Number | Name
1 | 14021740 | | SKS Kontakttechnik | SEB 2620 F6,3 RED | Sicherheitslaborbuchse Buchse ø 4 mm rot
1 | 14021739 | | SKS Kontakttechnik | SEB 2620 F6,3 BLACK | Sicherheitslaborbuchse Buchse ø 4 mm schwarz
15 | 30158301 | | RND Components | RND 210-00629 | LED-Reflektor 5mm
15 | 17510180 | | Vishay | TLLG 5400 | LED Grün 5 mm T-1 3/4
1 | 30064347 | | RND Components | RND 455-00126 | Kunststoffgehäuse 120x200x90mm Hellgrau Polycarbonat IP65
7 | 15519288 | | Lapp | SKINTOP ST-M 16X1,5 RAL 7001 SGY | Kabelverschraubung Polyamid M16 8mm Silbergrau

X1.2

X1.1

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
Zu X23

Zu X22

Zu X21

Zu X13

Zu X12

Zu X11

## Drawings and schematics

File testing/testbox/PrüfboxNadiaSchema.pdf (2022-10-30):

1 | 2 | 3 | 4 | 5 | 6 | 7 | 8

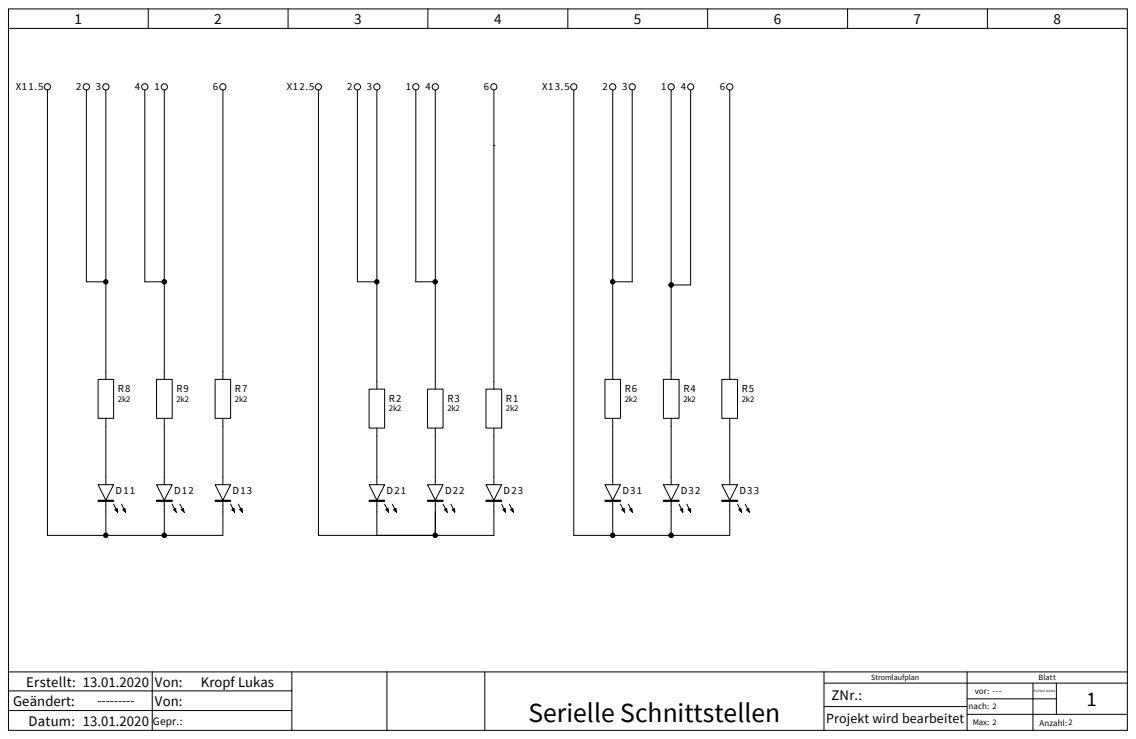
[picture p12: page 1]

1 | 2 | 3 | 4 | 5 | 6 | 7 | 8

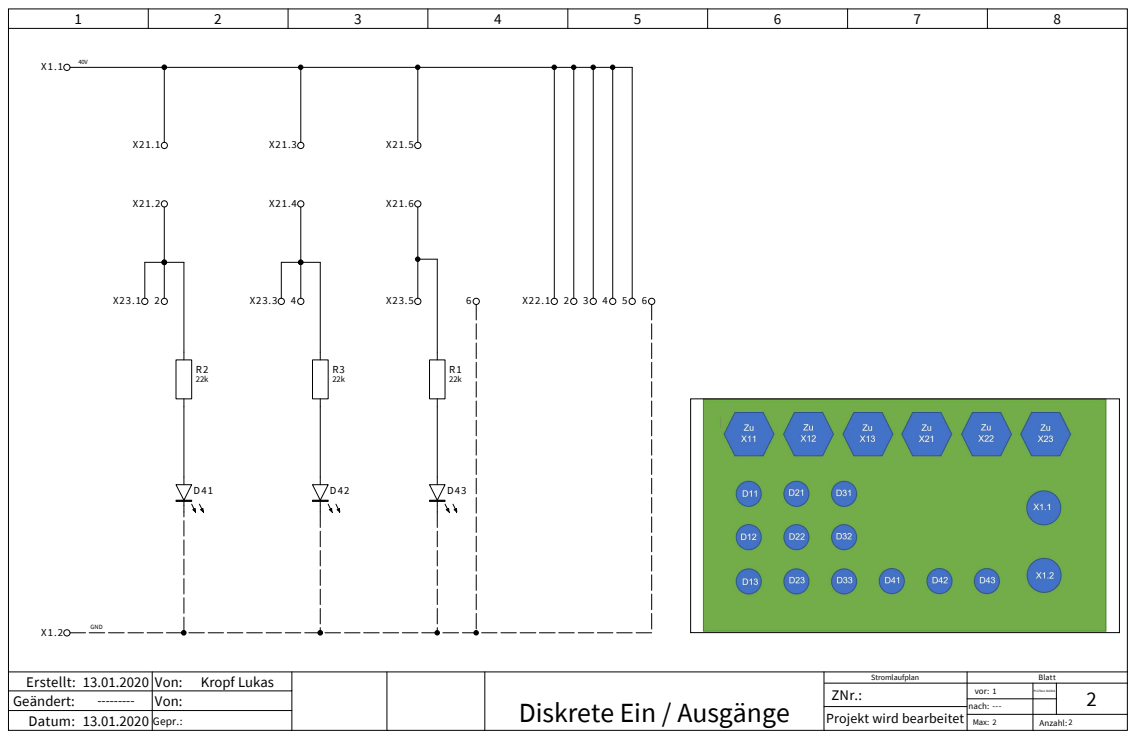
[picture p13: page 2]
GND; Erstellt: 13.01.2020; Geändert:; Diskrete Ein / Ausgänge; Kropf Lukas; Prüfbox NADIA; Blatt; Anzahl: 2; nach:; vor:; Max: 2; Datum: 13.01.2020; Von: Von: Gepr.:

Stromlaufplan
ZNr.:
Projekt wird bearbeitet

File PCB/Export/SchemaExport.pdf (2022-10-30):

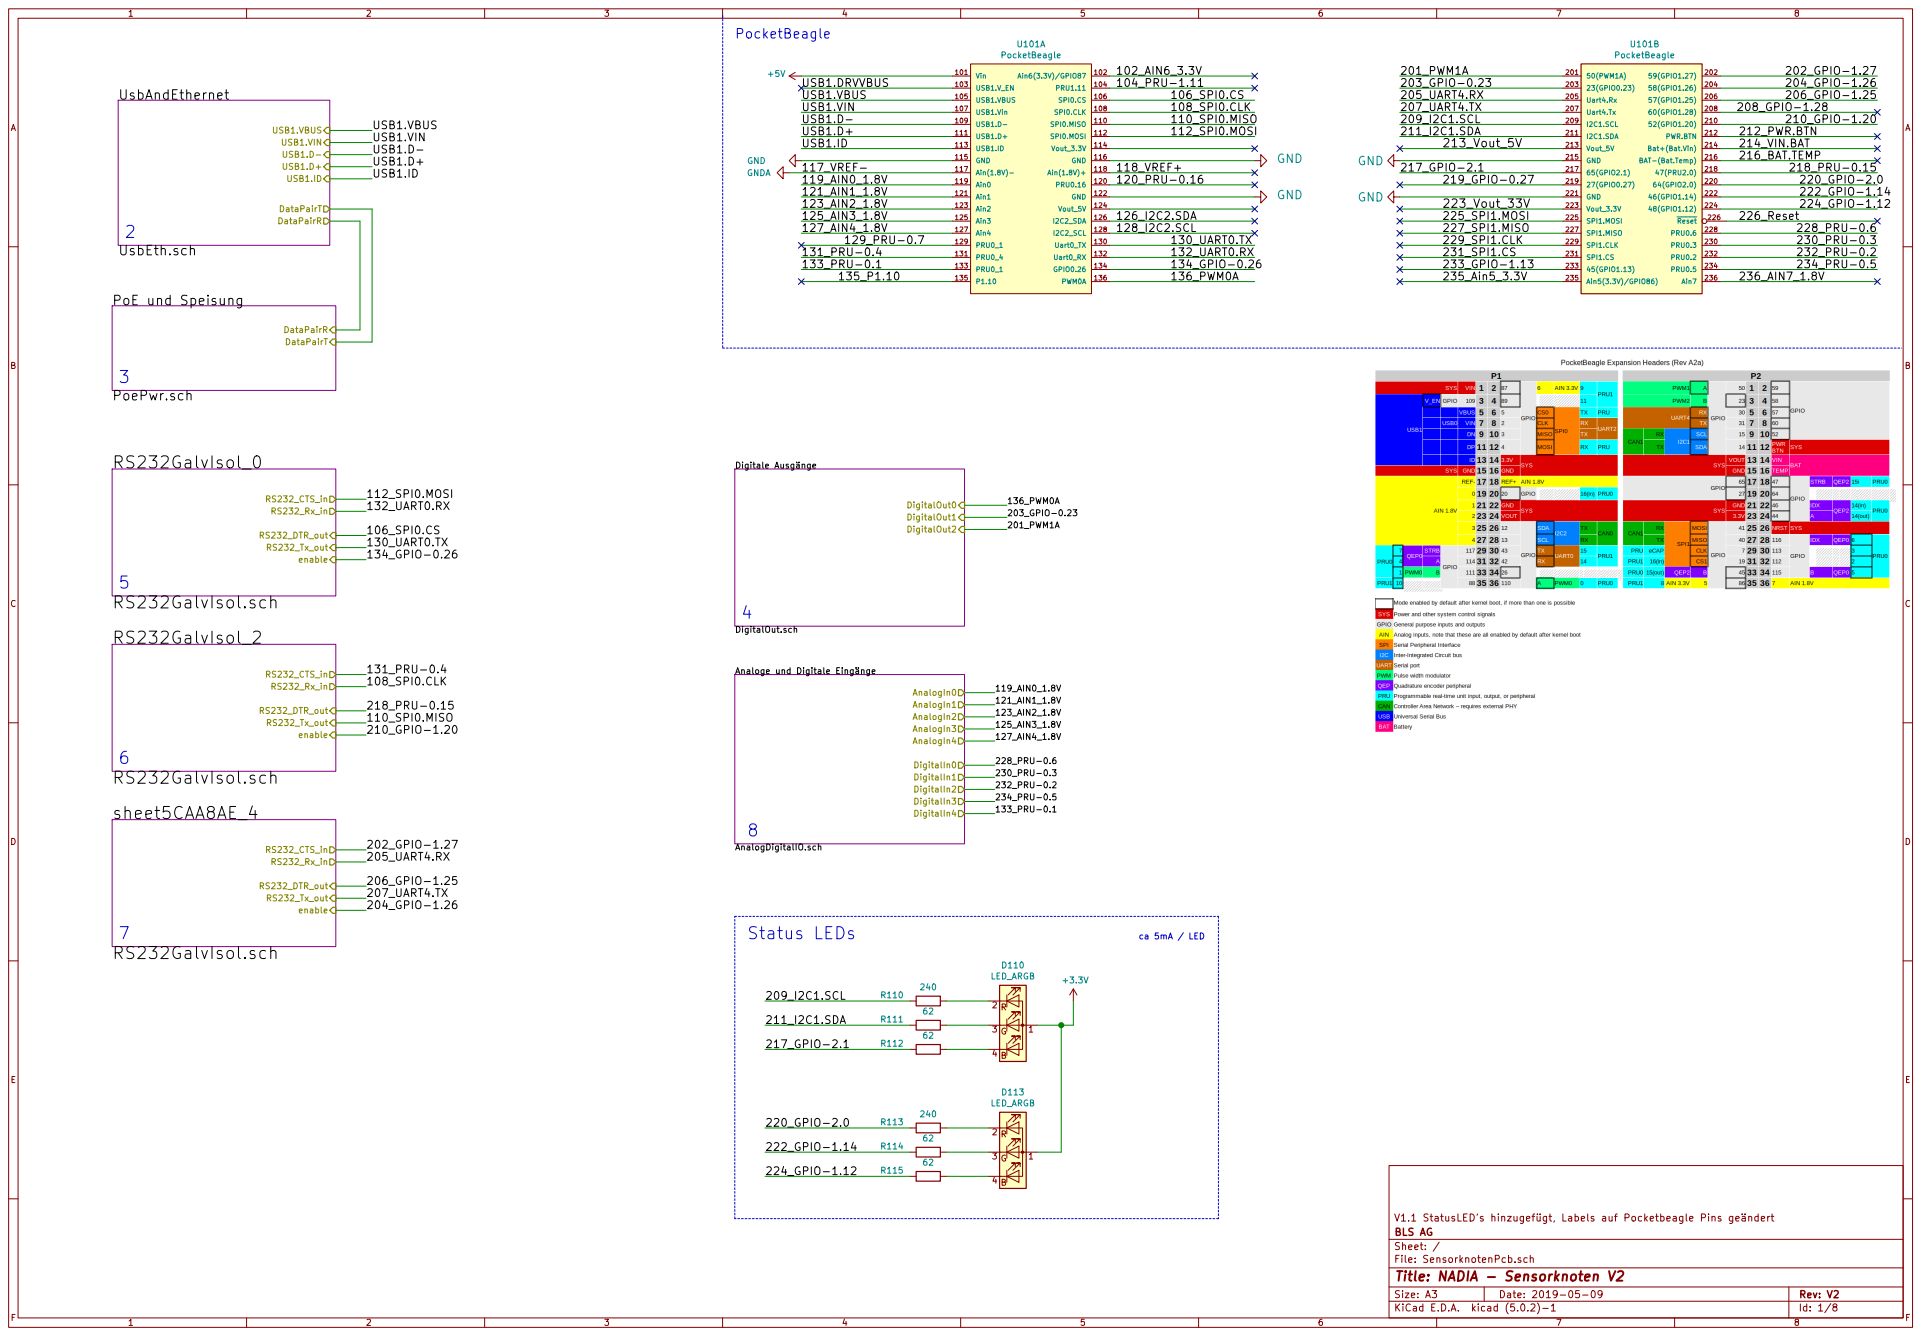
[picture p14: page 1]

USB1.VBUS DataPairT DataPairR PoE und Speisung

128_I2C2.SCL

130_UART0.TX

V1.1 StatusLED's hinzugefügt, Labels auf Pocketbeagle Pins geändert
File: SensorknotenPcb.sch Sheet: / BLS AG

Id: 1/8 Title: NADIA - Sensorknoten V2

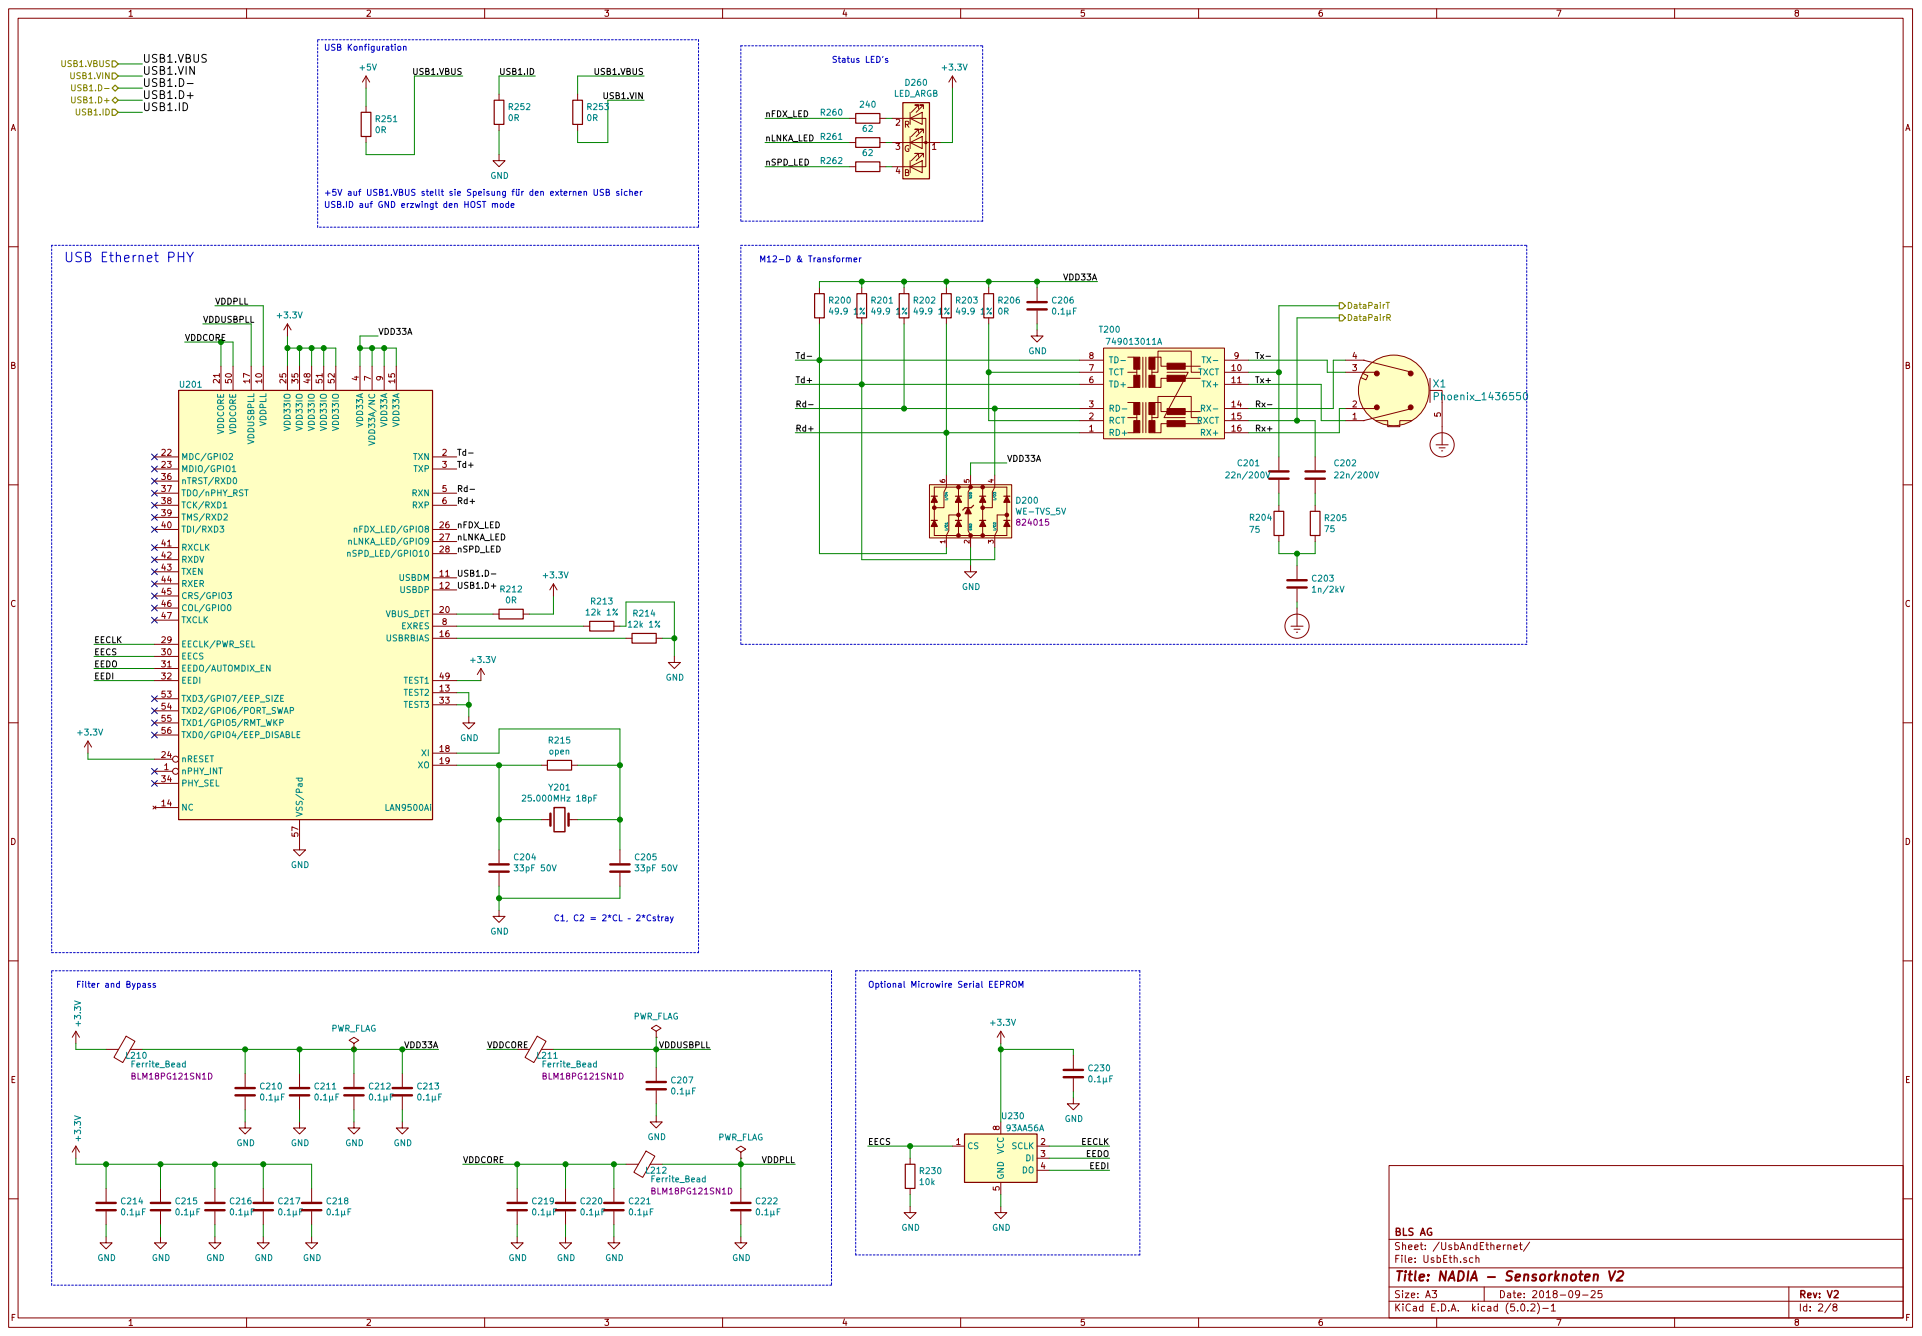
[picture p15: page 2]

USB1.ID USB Ethernet PHY
USB1.D+ USB1.D- USB1.VIN

4 TDI/RXD3 40 RXCLK 41 RXDV 42 TXEN 43 RXER 44 CRS/GPIO3 45 COL/GPIO0 46 TXCLK 47 VDD33IO 48 TEST1 49 RXN 5 VDDCORE 50 VDD33IO 51 VDD33IO 52 TXD3/GPIO7/EEP_SIZE 53 TXD2/GPIO6/PORT_SWAP 54 TXD1/GPIO5/RMT_WKP 55 TXD0/GPIO4/EEP_DISABLE 56 VSS/Pad 57 RXP 6 VDD33A/NC

Td- Td+ Rd- Rd+ USB1.D- USB1.D+

File: UsbEth.sch Sheet: /UsbAndEthernet/ BLS AG

Id: 2/8 Title: NADIA - Sensorknoten V2

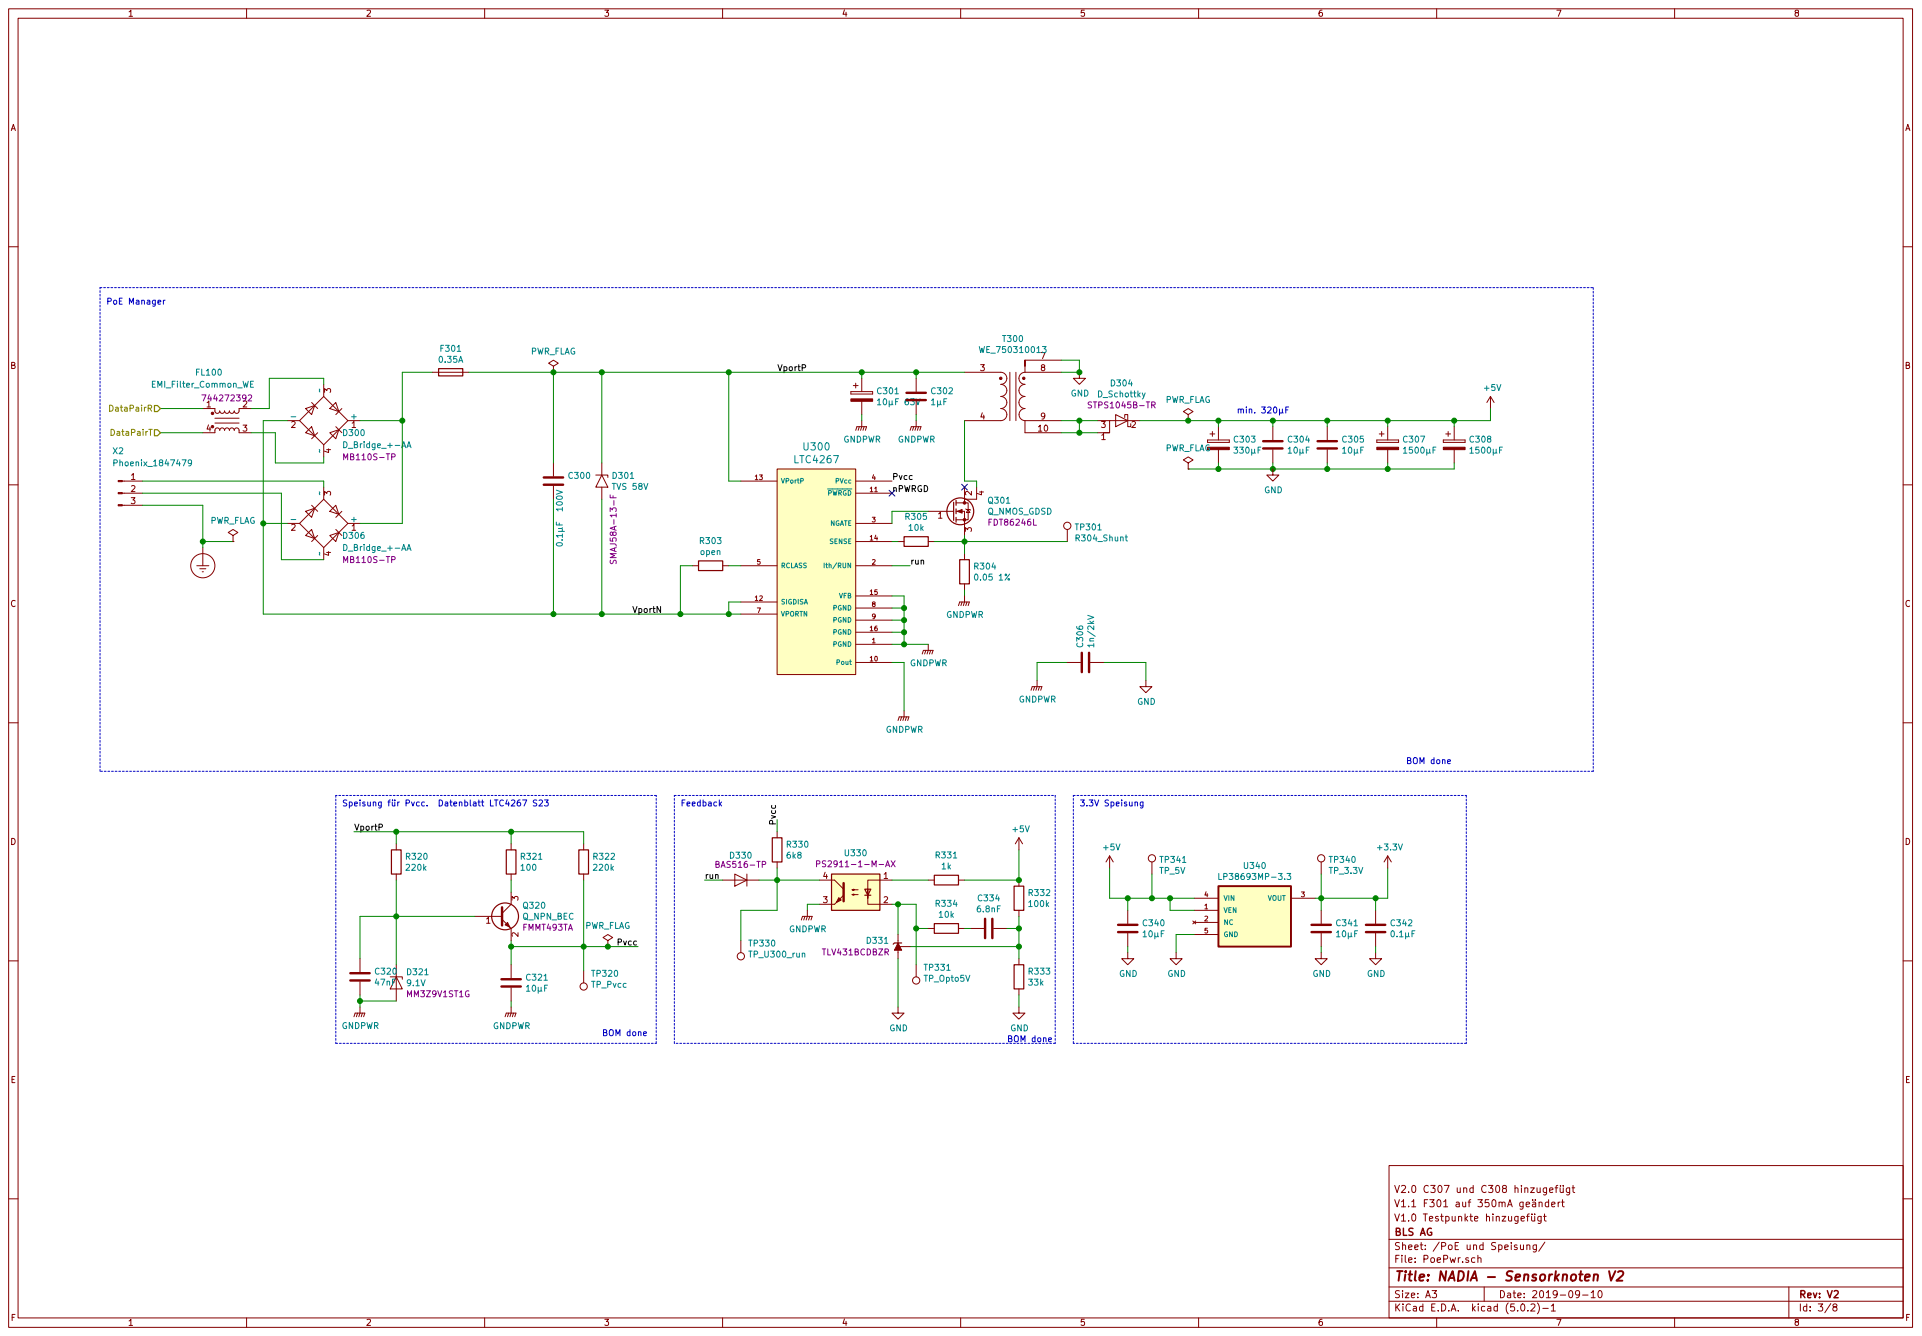
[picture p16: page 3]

V2.0 C307 und C308 hinzugefügt
V1.1 F301 auf 350mA geändert
V1.0 Testpunkte hinzugefügt
File: PoePwr.sch Sheet: /PoE und Speisung/ BLS AG

Id: 3/8 Title: NADIA - Sensorknoten V2

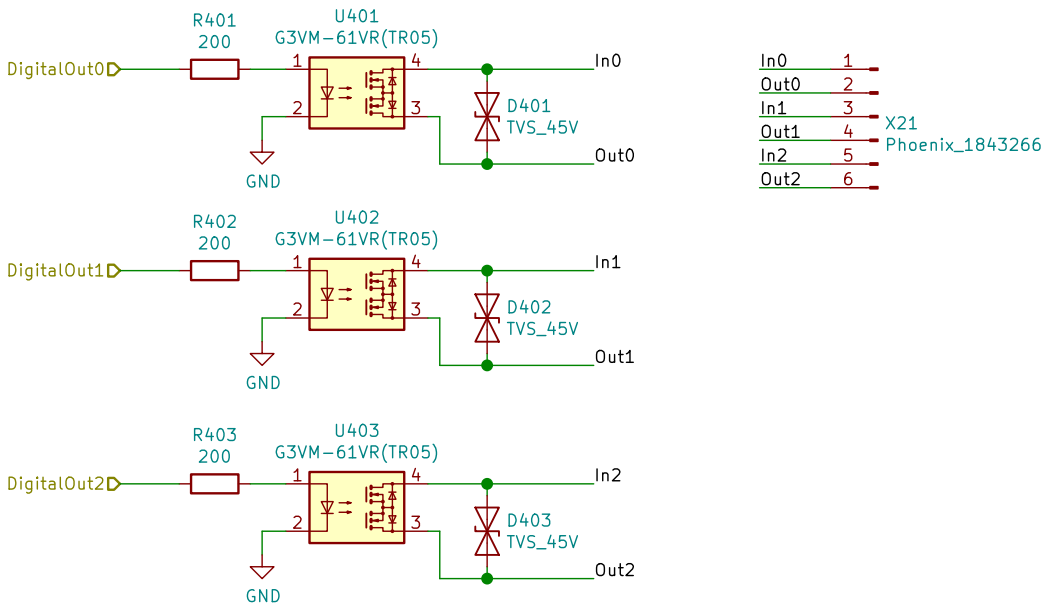
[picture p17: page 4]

V1.1 Ausgänge galvanisch voneinander getrennt, TVS mit 45V gewählt
Sheet: /Digitale Ausgänge/ BLS AG

File: DigitalOut.sch
Id: 4/8 Title: NADIA - Sensorknoten V2

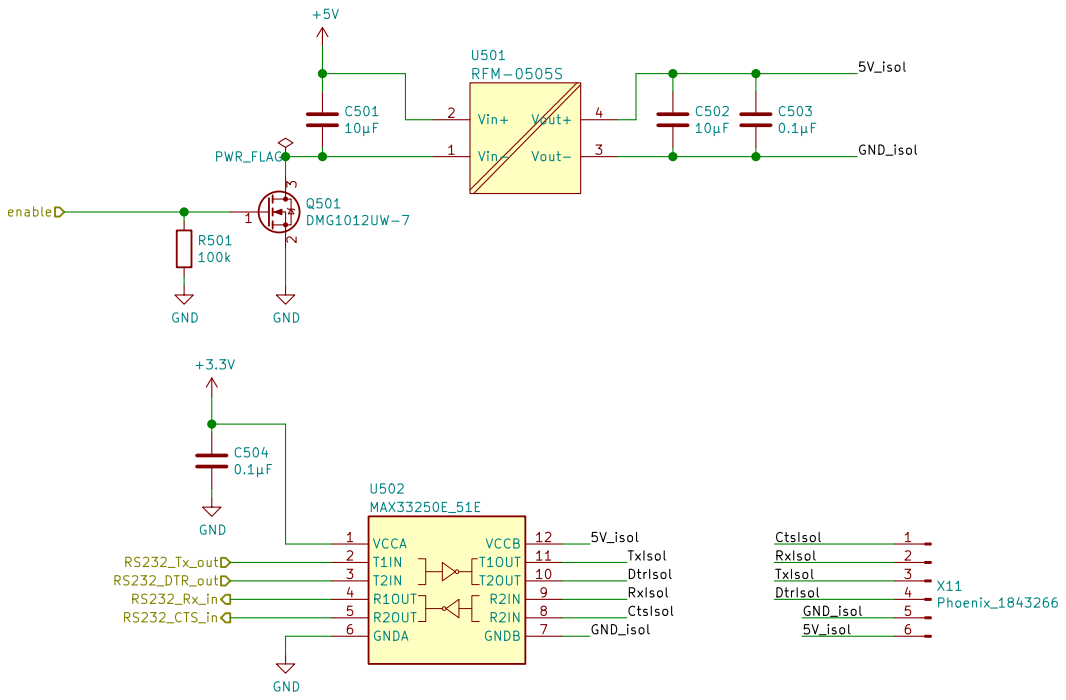
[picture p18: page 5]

File: RS232GalvIsol.sch Sheet: /RS232GalvIsol_0/ BLS AG

Id: 5/8 Title: NADIA - Sensorknoten V2

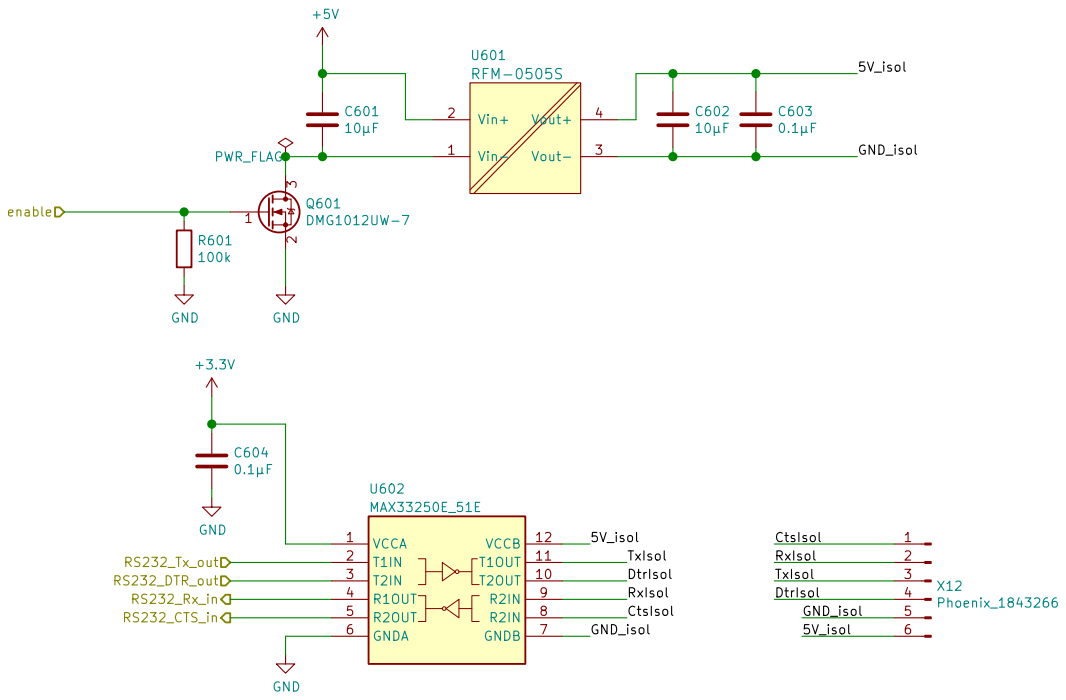
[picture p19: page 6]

File: RS232GalvIsol.sch Sheet: /RS232GalvIsol_2/ BLS AG

Id: 6/8 Title: NADIA - Sensorknoten V2

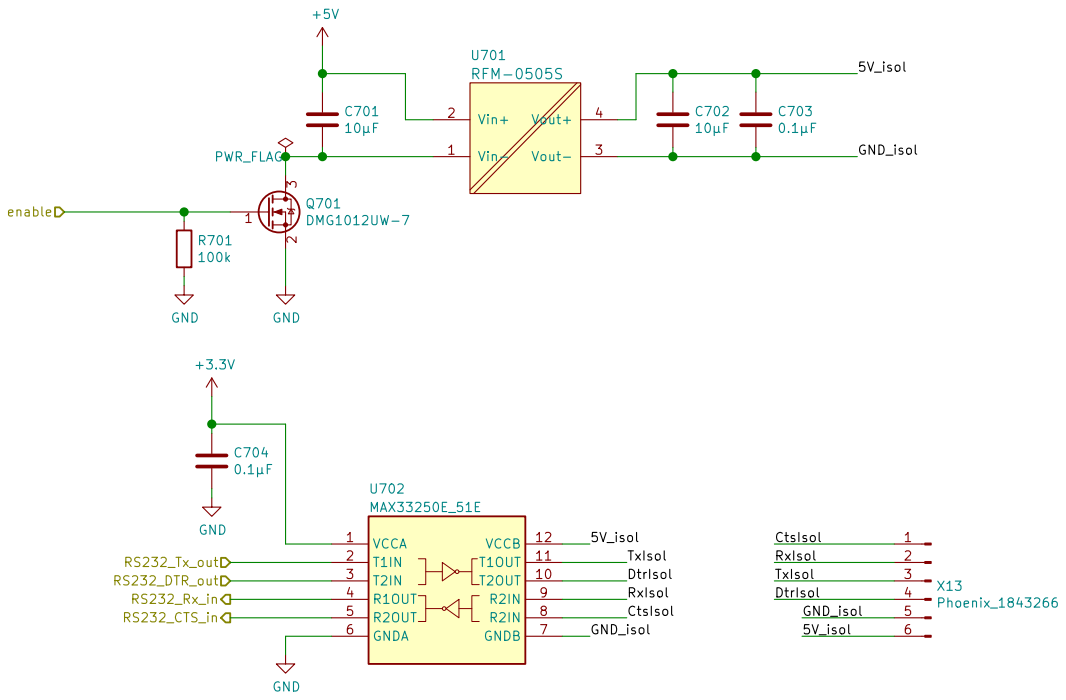
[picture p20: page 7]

File: RS232GalvIsol.sch Sheet: /sheet5CAA8AE_4/ BLS AG

Id: 7/8 Title: NADIA - Sensorknoten V2

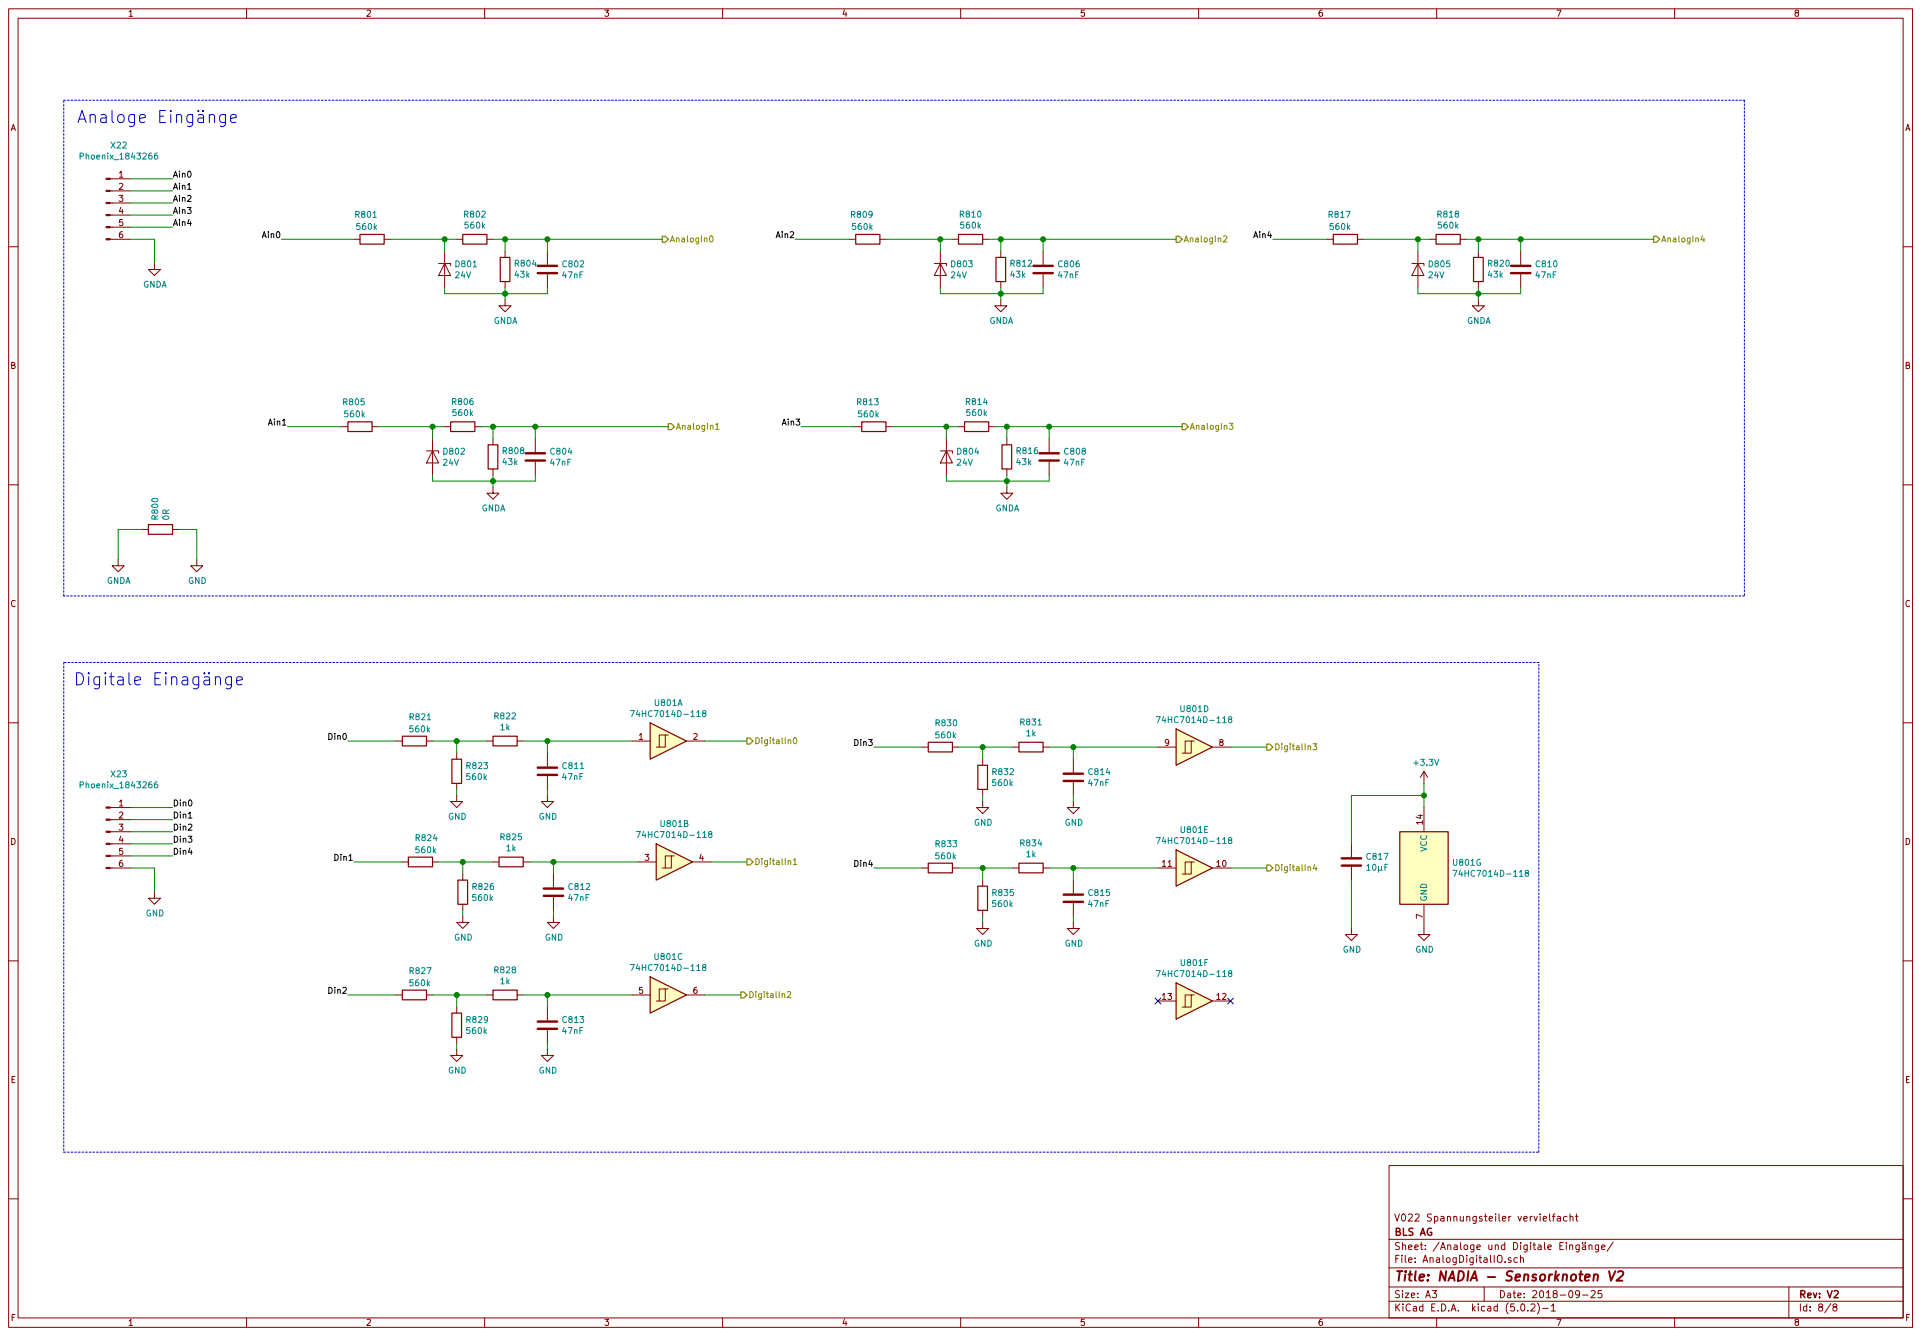
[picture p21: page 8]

V022 Spannungsteiler vervielfacht
Sheet: /Analoge und Digitale Eingänge/ BLS AG

File: AnalogDigitalIO.sch
Id: 8/8 Title: NADIA - Sensorknoten V2

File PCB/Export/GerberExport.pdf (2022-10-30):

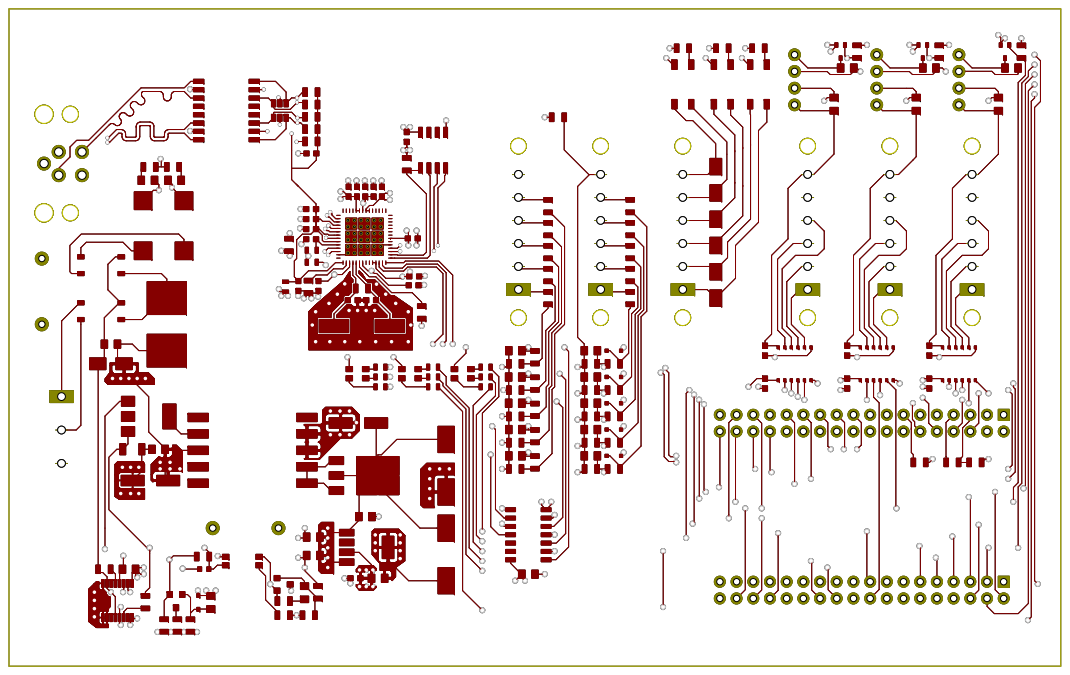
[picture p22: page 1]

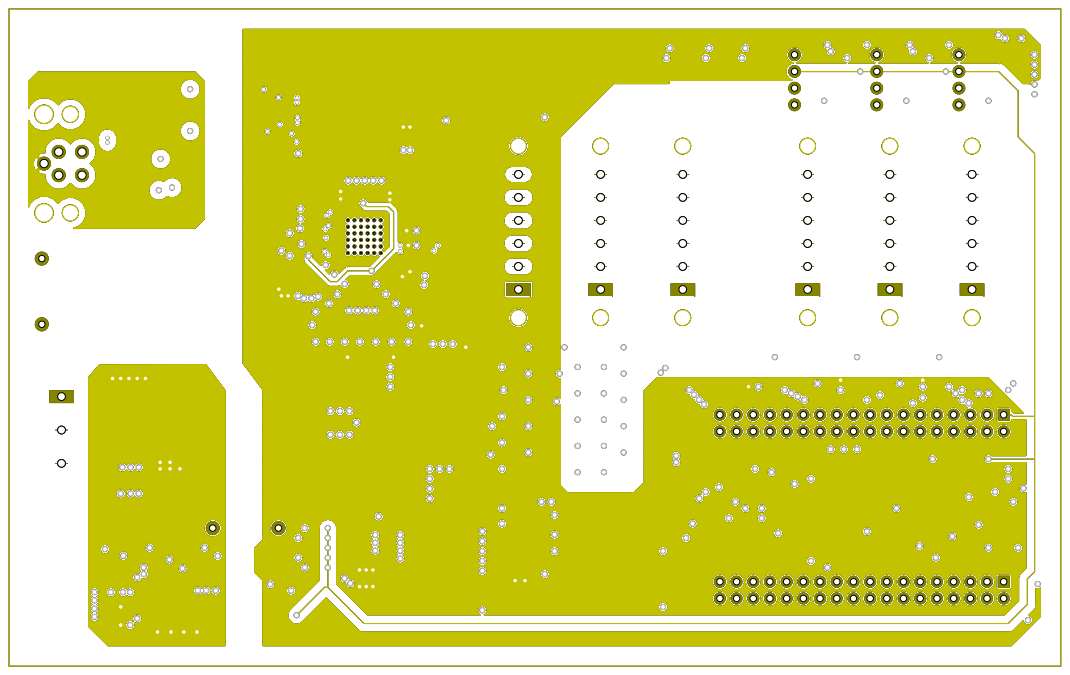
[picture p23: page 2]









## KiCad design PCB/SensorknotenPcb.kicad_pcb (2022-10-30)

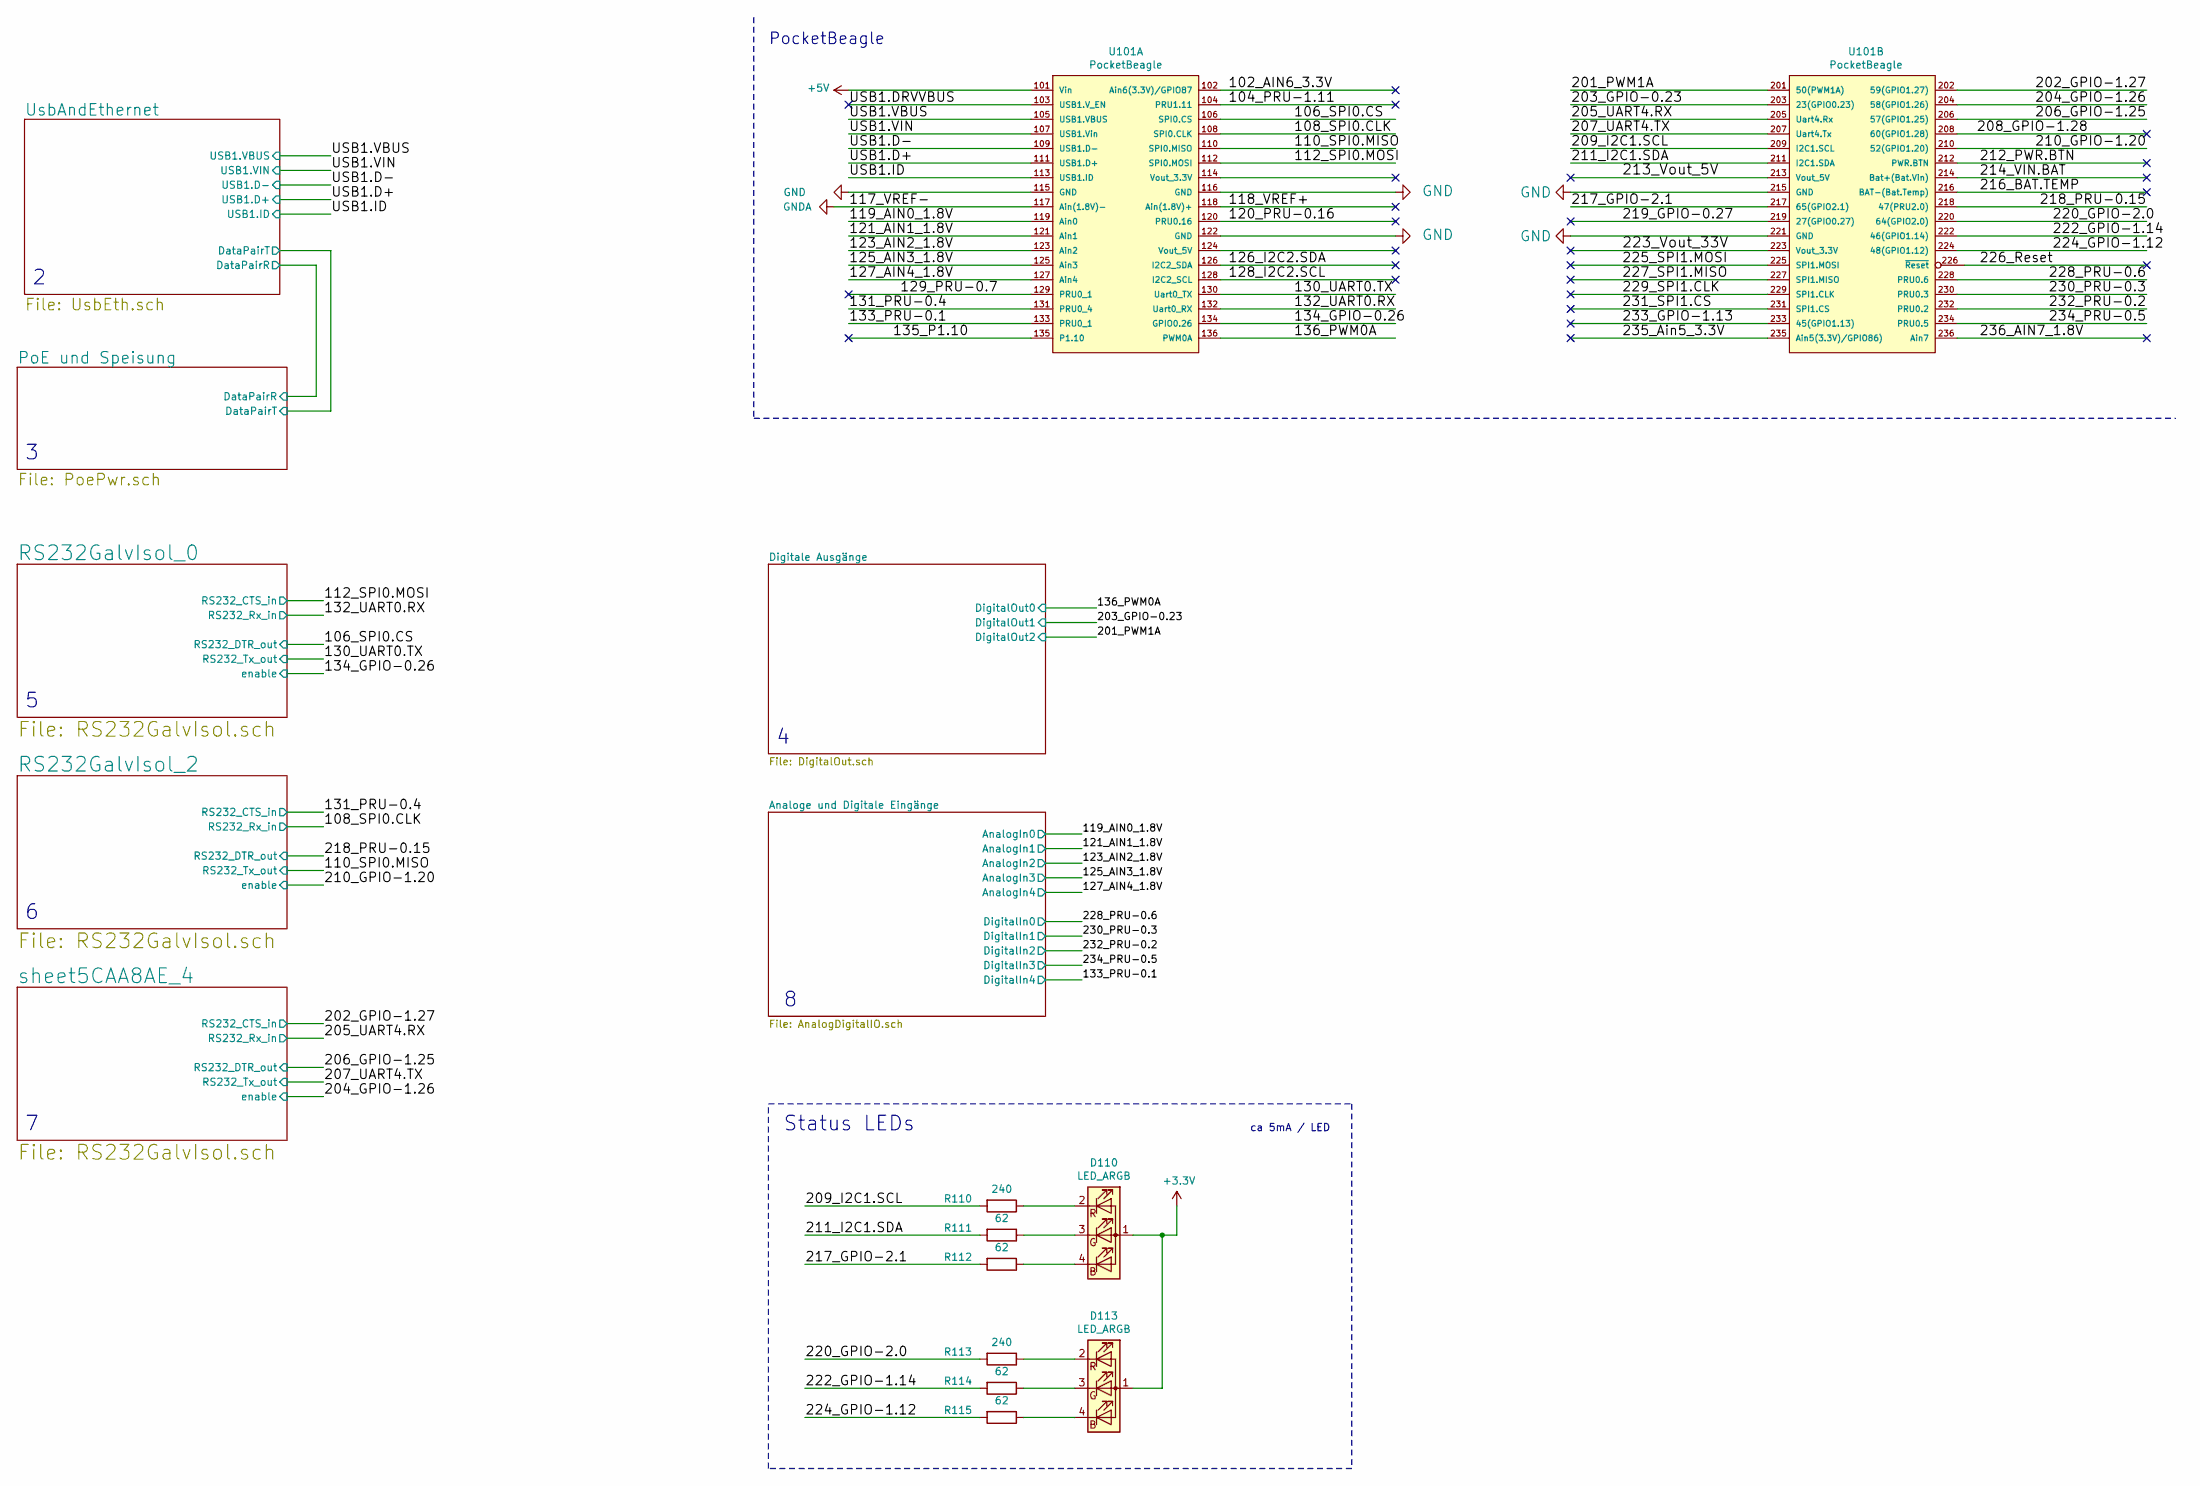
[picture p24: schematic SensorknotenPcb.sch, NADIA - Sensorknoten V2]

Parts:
D110, D113: LED_ARGB; LED_Cree-PLCC4_3.2x2.8mm_CCW; part-num CLV1L-FKB-CHMMQEHBB7673673
R110, R113: 240; R_0603; part-num ERJ-3GEYJ241V
R111, R112, R114, R115: 62; R_0603; part-num ERJ-3GEYJ620V
U101: PocketBeagle; part-num POCKETBEAGLE-SC-569;TSW-118-05-G-D;TSW-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

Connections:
+3V3: D110.1 (A), D113.1 (A); also elsewhere on the board
+5V: U101.101 (Vin); also elsewhere on the board
/102_AIN6_3.3V: U101.102 (Ain6(3.3V)/GPIO87)
/104_PRU-1.11: U101.104 (PRU1.11)
/106_SPI0.CS: U101.106 (SPI0.CS); also elsewhere on the board
/108_SPI0.CLK: U101.108 (SPI0.CLK); also elsewhere on the board
/110_SPI0.MISO: U101.110 (SPI0.MISO); also elsewhere on the board
/112_SPI0.MOSI: U101.112 (SPI0.MOSI); also elsewhere on the board
/118_VREF+: U101.118 (Ain(1.8V)+)
/119_AIN0_1.8V: U101.119 (Ain0); also elsewhere on the board
/120_PRU-0.16: U101.120 (PRU0.16)
/121_AIN1_1.8V: U101.121 (Ain1); also elsewhere on the board
/123_AIN2_1.8V: U101.123 (Ain2); also elsewhere on the board
/125_AIN3_1.8V: U101.125 (Ain3); also elsewhere on the board
/126_I2C2.SDA: U101.126 (I2C2_SDA)
/127_AIN4_1.8V: U101.127 (Ain4); also elsewhere on the board
/128_I2C2.SCL: U101.128 (I2C2_SCL)
/129_PRU-0.7: U101.129 (PRU0_1)
/130_UART0.TX: U101.130 (Uart0_TX); also elsewhere on the board
/131_PRU-0.4: U101.131 (PRU0_4); also elsewhere on the board
/132_UART0.RX: U101.132 (Uart0_RX); also elsewhere on the board
/133_PRU-0.1: U101.133 (PRU0_1); also elsewhere on the board
/134_GPIO-0.26: U101.134 (GPIO0.26); also elsewhere on the board
/135_P1.10: U101.135 (P1.10)
/136_PWM0A: U101.136 (PWM0A); also elsewhere on the board
/201_PWM1A: U101.201 (50(PWM1A)); also elsewhere on the board
/202_GPIO-1.27: U101.202 (59(GPIO1.27)); also elsewhere on the board
/203_GPIO-0.23: U101.203 (23(GPIO0.23)); also elsewhere on the board
/204_GPIO-1.26: U101.204 (58(GPIO1.26)); also elsewhere on the board
/205_UART4.RX: U101.205 (Uart4.Rx); also elsewhere on the board
/206_GPIO-1.25: U101.206 (57(GPIO1.25)); also elsewhere on the board
/207_UART4.TX: U101.207 (Uart4.Tx); also elsewhere on the board
/208_GPIO-1.28: U101.208 (60(GPIO1.28))
/209_I2C1.SCL: R110.2, U101.209 (I2C1.SCL)
/210_GPIO-1.20: U101.210 (52(GPIO1.20)); also elsewhere on the board
/211_I2C1.SDA: R111.2, U101.211 (I2C1.SDA)
/212_PWR.BTN: U101.212 (PWR.BTN)
/213_Vout_5V: U101.213 (Vout_5V)
/214_VIN.BAT: U101.214 (Bat+(Bat.Vin))
/216_BAT.TEMP: U101.216 (BAT-(Bat.Temp))
/217_GPIO-2.1: R112.2, U101.217 (65(GPIO2.1))
/218_PRU-0.15: U101.218 (47(PRU2.0)); also elsewhere on the board
/219_GPIO-0.27: U101.219 (27(GPIO0.27))
/220_GPIO-2.0: R113.2, U101.220 (64(GPIO2.0))
/222_GPIO-1.14: R114.2, U101.222 (46(GPIO1.14))
/223_Vout_33V: U101.223 (Vout_3.3V)
/224_GPIO-1.12: R115.2, U101.224 (48(GPIO1.12))
/225_SPI1.MOSI: U101.225 (SPI1.MOSI)
/226_Reset: U101.226 (~Reset)
/227_SPI1.MISO: U101.227 (SPI1.MISO)
/228_PRU-0.6: U101.228 (PRU0.6); also elsewhere on the board
/229_SPI1.CLK: U101.229 (SPI1.CLK)
/230_PRU-0.3: U101.230 (PRU0.3); also elsewhere on the board
/231_SPI1.CS: U101.231 (SPI1.CS)
/232_PRU-0.2: U101.232 (PRU0.2); also elsewhere on the board
/233_GPIO-1.13: U101.233 (45(GPIO1.13))
/234_PRU-0.5: U101.234 (PRU0.5); also elsewhere on the board
/235_Ain5_3.3V: U101.235 (Ain5(3.3V)/GPIO86))
/236_AIN7_1.8V: U101.236 (Ain7)
/USB1.D+: U101.111 (USB1.D+); also elsewhere on the board
/USB1.D-: U101.109 (USB1.D-); also elsewhere on the board
/USB1.DRVVBUS: U101.103 (USB1.V_EN)
/USB1.ID: U101.113 (USB1.ID); also elsewhere on the board
/USB1.VBUS: U101.105 (USB1.VBUS); also elsewhere on the board
/USB1.VIN: U101.107 (USB1.Vin); also elsewhere on the board
GND: U101.115 (GND), U101.116 (GND), U101.122 (GND), U101.215 (GND), U101.221 (GND); also elsewhere on the board
GNDA: U101.117 (Ain(1.8V)-); also elsewhere on the board
unnamed: D110.2 (RK), R110.1
unnamed: D110.3 (GK), R111.1
unnamed: D110.4 (BK), R112.1
unnamed: D113.2 (RK), R113.1
unnamed: D113.3 (GK), R114.1
unnamed: D113.4 (BK), R115.1

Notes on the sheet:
PocketBeagle
Status LEDs
ca 5mA / LED

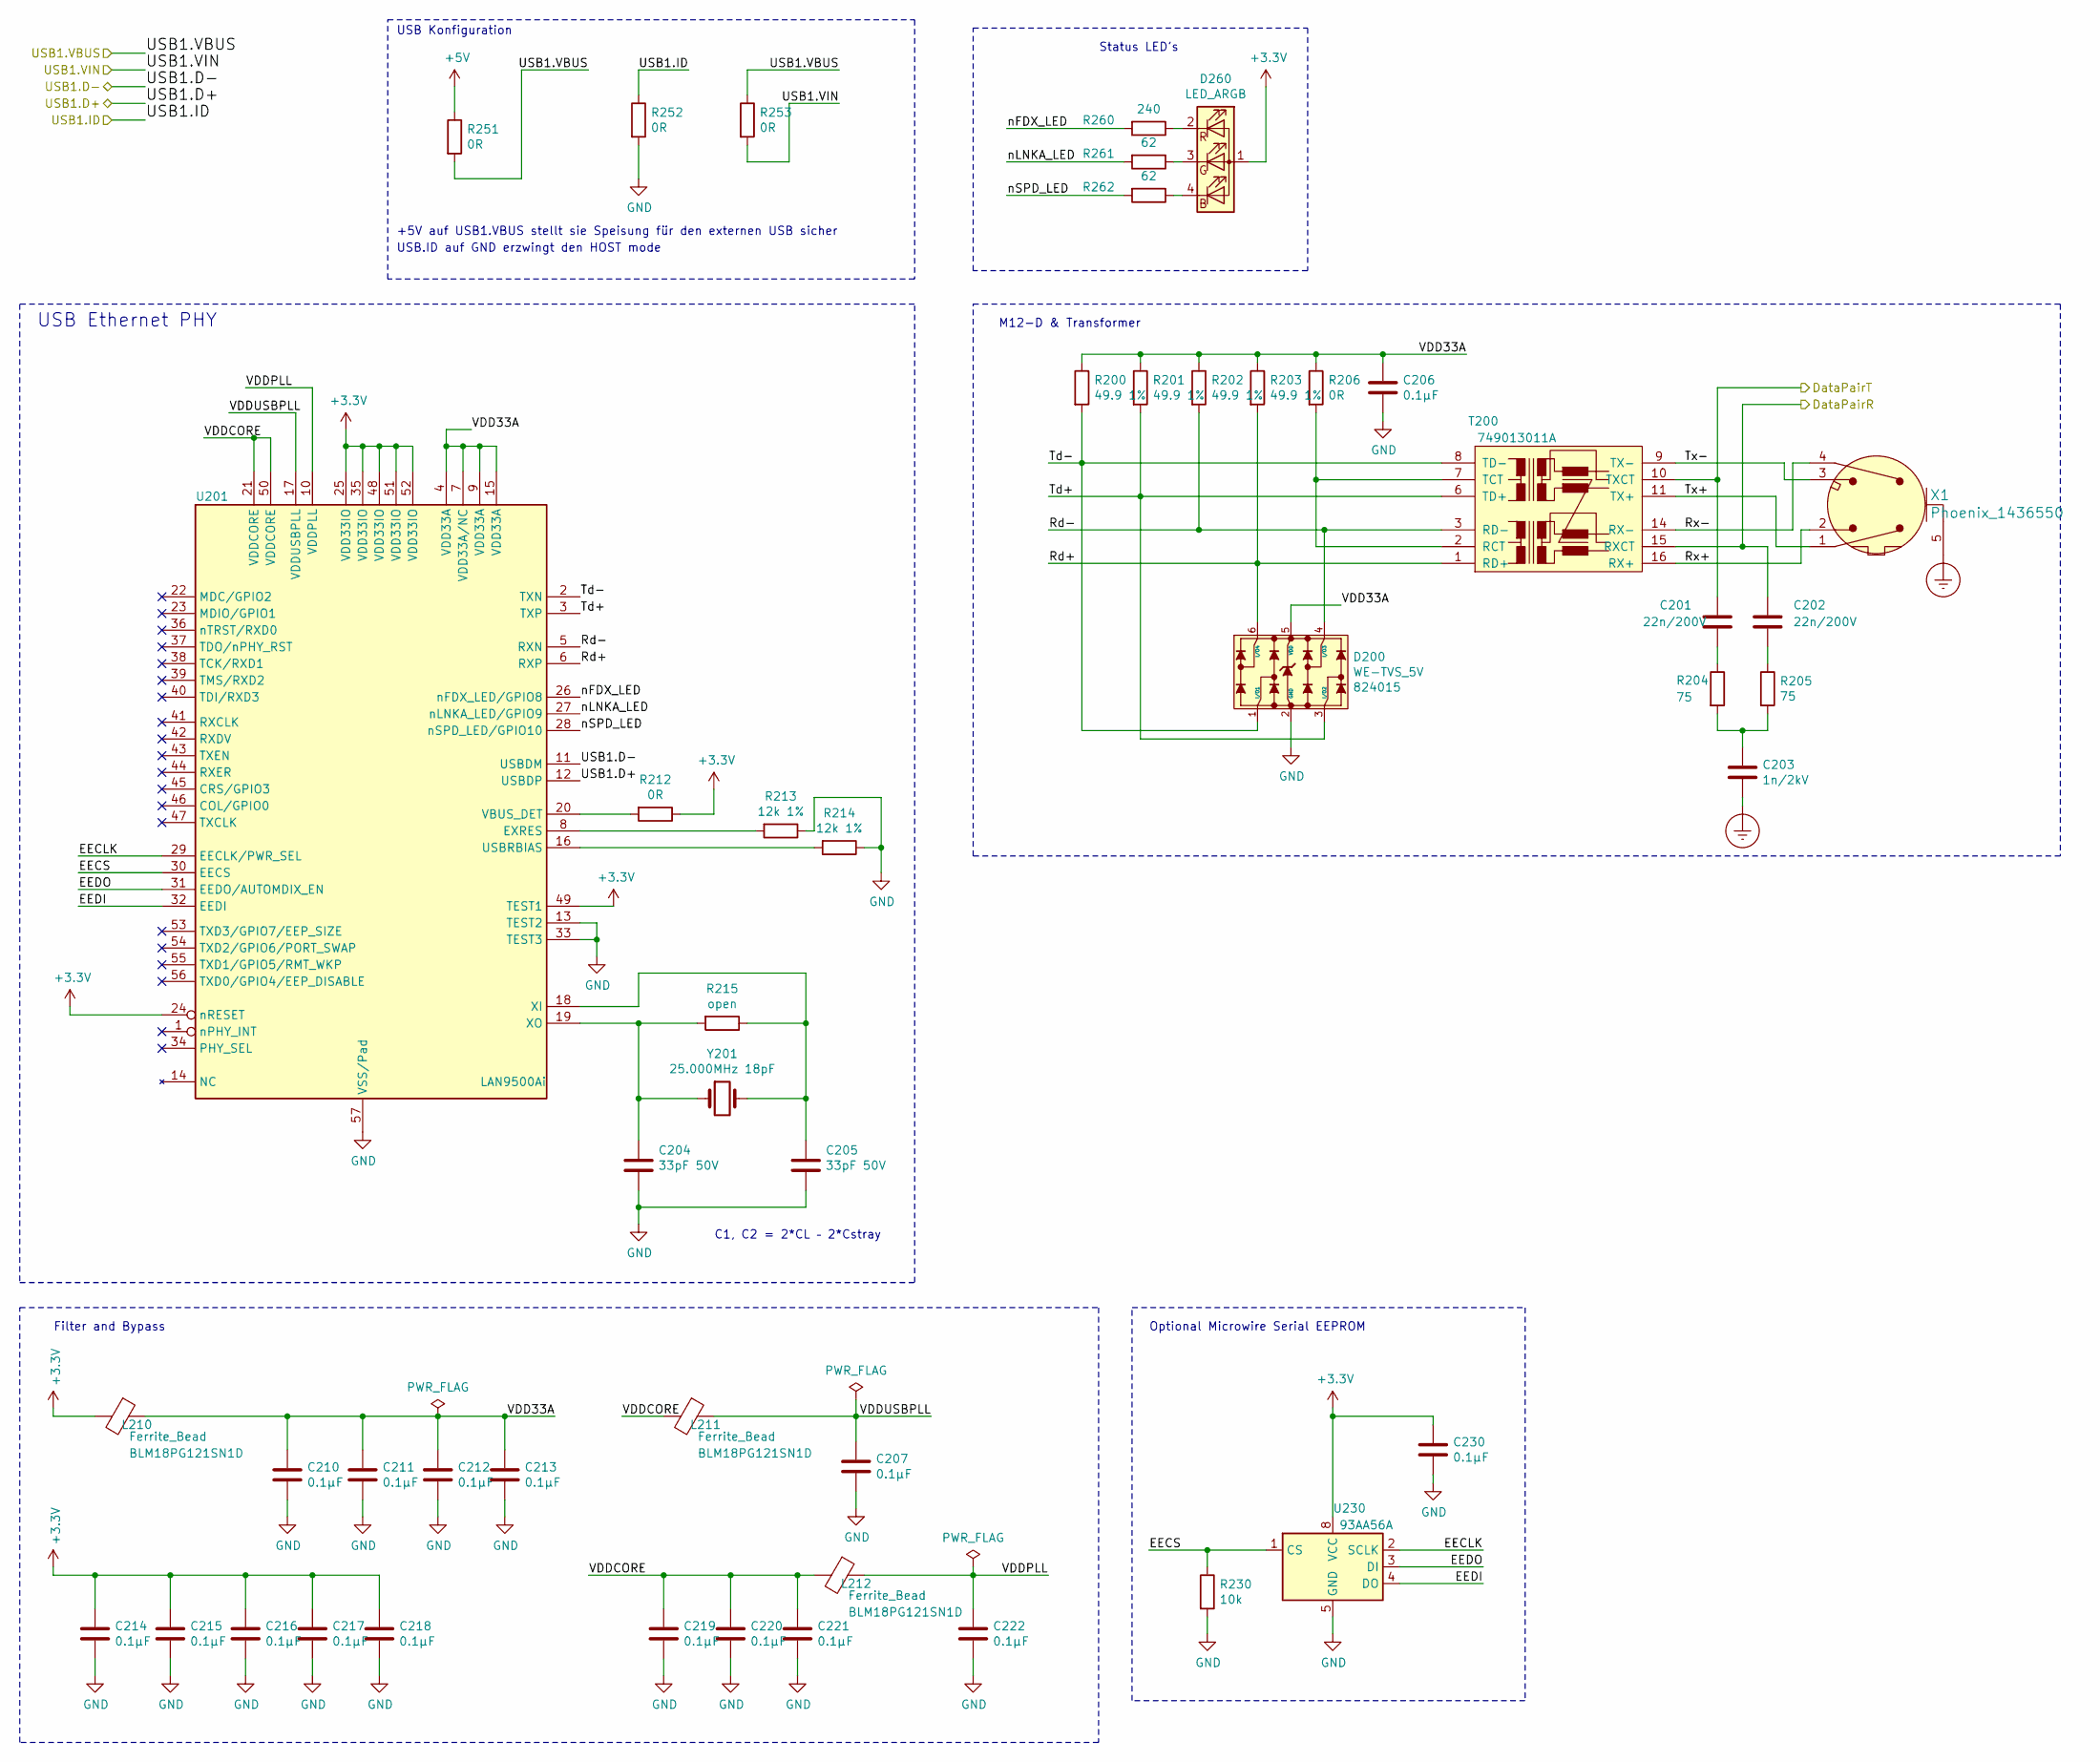
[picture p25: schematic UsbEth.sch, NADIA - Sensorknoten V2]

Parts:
C201, C202: 22n/200V; C_0805; part-num 08052C223KAT2A
C203: 1n/2kV; C_Rect_L13.0mm_W4.0mm_P10.00mm_FKS3_FKP3_MKS4; part-num MKS4U011003C00KSSD
C204, C205: 33pF 50V; C_0603; part-num CL10C330FB8NNNC
C206, C207, C210, C211, C212, C213, C214, C215, C216, C217, C218, C219, C220, C221, C222, C230: 0.1µF; C_0603; part-num CL10B104KO8NNNC
D200: WE-TVS_5V; SOT-23-6; part-num 824015
D260: LED_ARGB; LED_Cree-PLCC4_3.2x2.8mm_CCW; part-num CLV1L-FKB-CHMMQEHBB7673673
L210, L211, L212: Ferrite_Bead; L_0603; part-num BLM18PG121SN1D
R200, R201, R202, R203: 49.9 1%; R_0805; part-num ERJ-6ENF49R9V
R204, R205: 75; R_0805; part-num ERJ-6ENF75R0V
R206, R212, R251, R252, R253: 0R; R_0805; part-num ERJ-6GEY0R00V
R213, R214: 12k 1%; R_0805; part-num ERJ-6ENF1202V
R215: open; R_0805; part-num DNP
R230: 10k; R_0805; part-num ERJ-6ENF1002V
R260: 240; R_0603; part-num ERJ-3GEYJ241V
R261, R262: 62; R_0603; part-num ERJ-3GEYJ620V
T200: 749013011A; WE-LAN_PoE_749013011A; part-num 749013011A
U201: LAN9500Ai; QFN50P800X800X120-56N; part-num LAN9500A-ABZJ-TR
U230: 93AA56A; SOIC-8_3.9x4.9mm_Pitch1.27mm; part-num 93AA56AT-I/SN
X1: Phoenix_1436550; Phoenix_SACC-DSIV-M12FSD-4CON-L90; part-num 1436550
Y201: 25.000MHz 18pF; Crystal_SMD_HC49-SD; part-num ABLS2-25.000MHZ-D4YF-T

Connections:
+3V3: C214.1, C215.1, C216.1, C217.1, C218.1, C230.1, D260.1 (A), L210.2, R212.1, U201.24 (nRESET), U201.25 (VDD33IO), U201.35 (VDD33IO), U201.48 (VDD33IO), U201.49 (TEST1), U201.51 (VDD33IO), U201.52 (VDD33IO), U230.8 (VCC); also elsewhere on the board
+5V: R251.1; also elsewhere on the board
/PoE und Speisung/DataPairR: C202.1, T200.15 (RXCT); also elsewhere on the board
/PoE und Speisung/DataPairT: C201.1, T200.10 (TXCT); also elsewhere on the board
/USB1.D+: U201.12 (USBDP); also elsewhere on the board
/USB1.D-: U201.11 (USBDM); also elsewhere on the board
/USB1.ID: R252.1; also elsewhere on the board
/USB1.VBUS: R251.2, R253.1; also elsewhere on the board
/USB1.VIN: R253.2; also elsewhere on the board
/UsbAndEthernet/EECLK: U201.29 (EECLK/PWR_SEL), U230.2 (SCLK)
/UsbAndEthernet/EECS: R230.1, U201.30 (EECS), U230.1 (CS)
/UsbAndEthernet/EEDI: U201.32 (EEDI), U230.4 (DO)
/UsbAndEthernet/EEDO: U201.31 (EEDO/AUTOMDIX_EN), U230.3 (DI)
/UsbAndEthernet/Rd+: D200.6 (I/O4), R203.2, T200.1 (RD+), U201.6 (RXP)
/UsbAndEthernet/Rd-: D200.4 (I/O3), R202.2, T200.3 (RD-), U201.5 (RXN)
/UsbAndEthernet/Rx+: T200.16 (RX+), X1.2
/UsbAndEthernet/Rx-: T200.14 (RX-), X1.4
/UsbAndEthernet/Td+: D200.3 (I/O2), R201.2, T200.6 (TD+), U201.3 (TXP)
/UsbAndEthernet/Td-: D200.1 (I/O1), R200.2, T200.8 (TD-), U201.2 (TXN)
/UsbAndEthernet/Tx+: T200.11 (TX+), X1.1
/UsbAndEthernet/Tx-: T200.9 (TX-), X1.3
/UsbAndEthernet/VDD33A: C206.1, C210.1, C211.1, C212.1, C213.1, D200.5 (VDD), L210.1, R200.1, R201.1, R202.1, R203.1, R206.1, U201.4 (VDD33A), U201.7 (VDD33A/NC), U201.9 (VDD33A), U201.15 (VDD33A)
/UsbAndEthernet/VDDCORE: C219.1, C220.1, C221.1, L211.2, L212.2, U201.21 (VDDCORE), U201.50 (VDDCORE)
/UsbAndEthernet/VDDPLL: C222.1, L212.1, U201.10 (VDDPLL)
/UsbAndEthernet/VDDUSBPLL: C207.1, L211.1, U201.17 (VDDUSBPLL)
/UsbAndEthernet/nFDX_LED: R260.2, U201.26 (nFDX_LED/GPIO8)
/UsbAndEthernet/nLNKA_LED: R261.2, U201.27 (nLNKA_LED/GPIO9)
/UsbAndEthernet/nSPD_LED: R262.2, U201.28 (nSPD_LED/GPIO10)
Earth_Protective: C203.2, X1.5; also elsewhere on the board
GND: C204.2, C205.2, C206.2, C207.2, C210.2, C211.2, C212.2, C213.2, C214.2, C215.2, C216.2, C217.2, C218.2, C219.2, C220.2, C221.2, C222.2, C230.2, D200.2 (GND), R213.1, R214.1, R230.2, R252.2, U201.13 (TEST2), U201.33 (TEST3), U201.57 (VSS/Pad), U230.5 (GND); also elsewhere on the board
unnamed: C201.2, R204.1
unnamed: C202.2, R205.1
unnamed: C203.1, R204.2, R205.2
unnamed: C204.1, R215.2, U201.19 (XO), Y201.1
unnamed: C205.1, R215.1, U201.18 (XI), Y201.2
unnamed: D260.2 (RK), R260.1
unnamed: D260.3 (GK), R261.1
unnamed: D260.4 (BK), R262.1
unnamed: R206.2, T200.2 (RCT), T200.7 (TCT)
unnamed: R212.2, U201.20 (VBUS_DET)
unnamed: R213.2, U201.8 (EXRES)
unnamed: R214.2, U201.16 (USBRBIAS)

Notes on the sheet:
Filter and Bypass
Status LED's
Optional Microwire Serial EEPROM
USB Konfiguration
USB Ethernet PHY
USB.ID auf GND erzwingt den HOST mode
M12-D & Transformer
C1, C2 = 2*CL – 2*Cstray
+5V auf USB1.VBUS stellt sie Speisung für den externen USB sicher

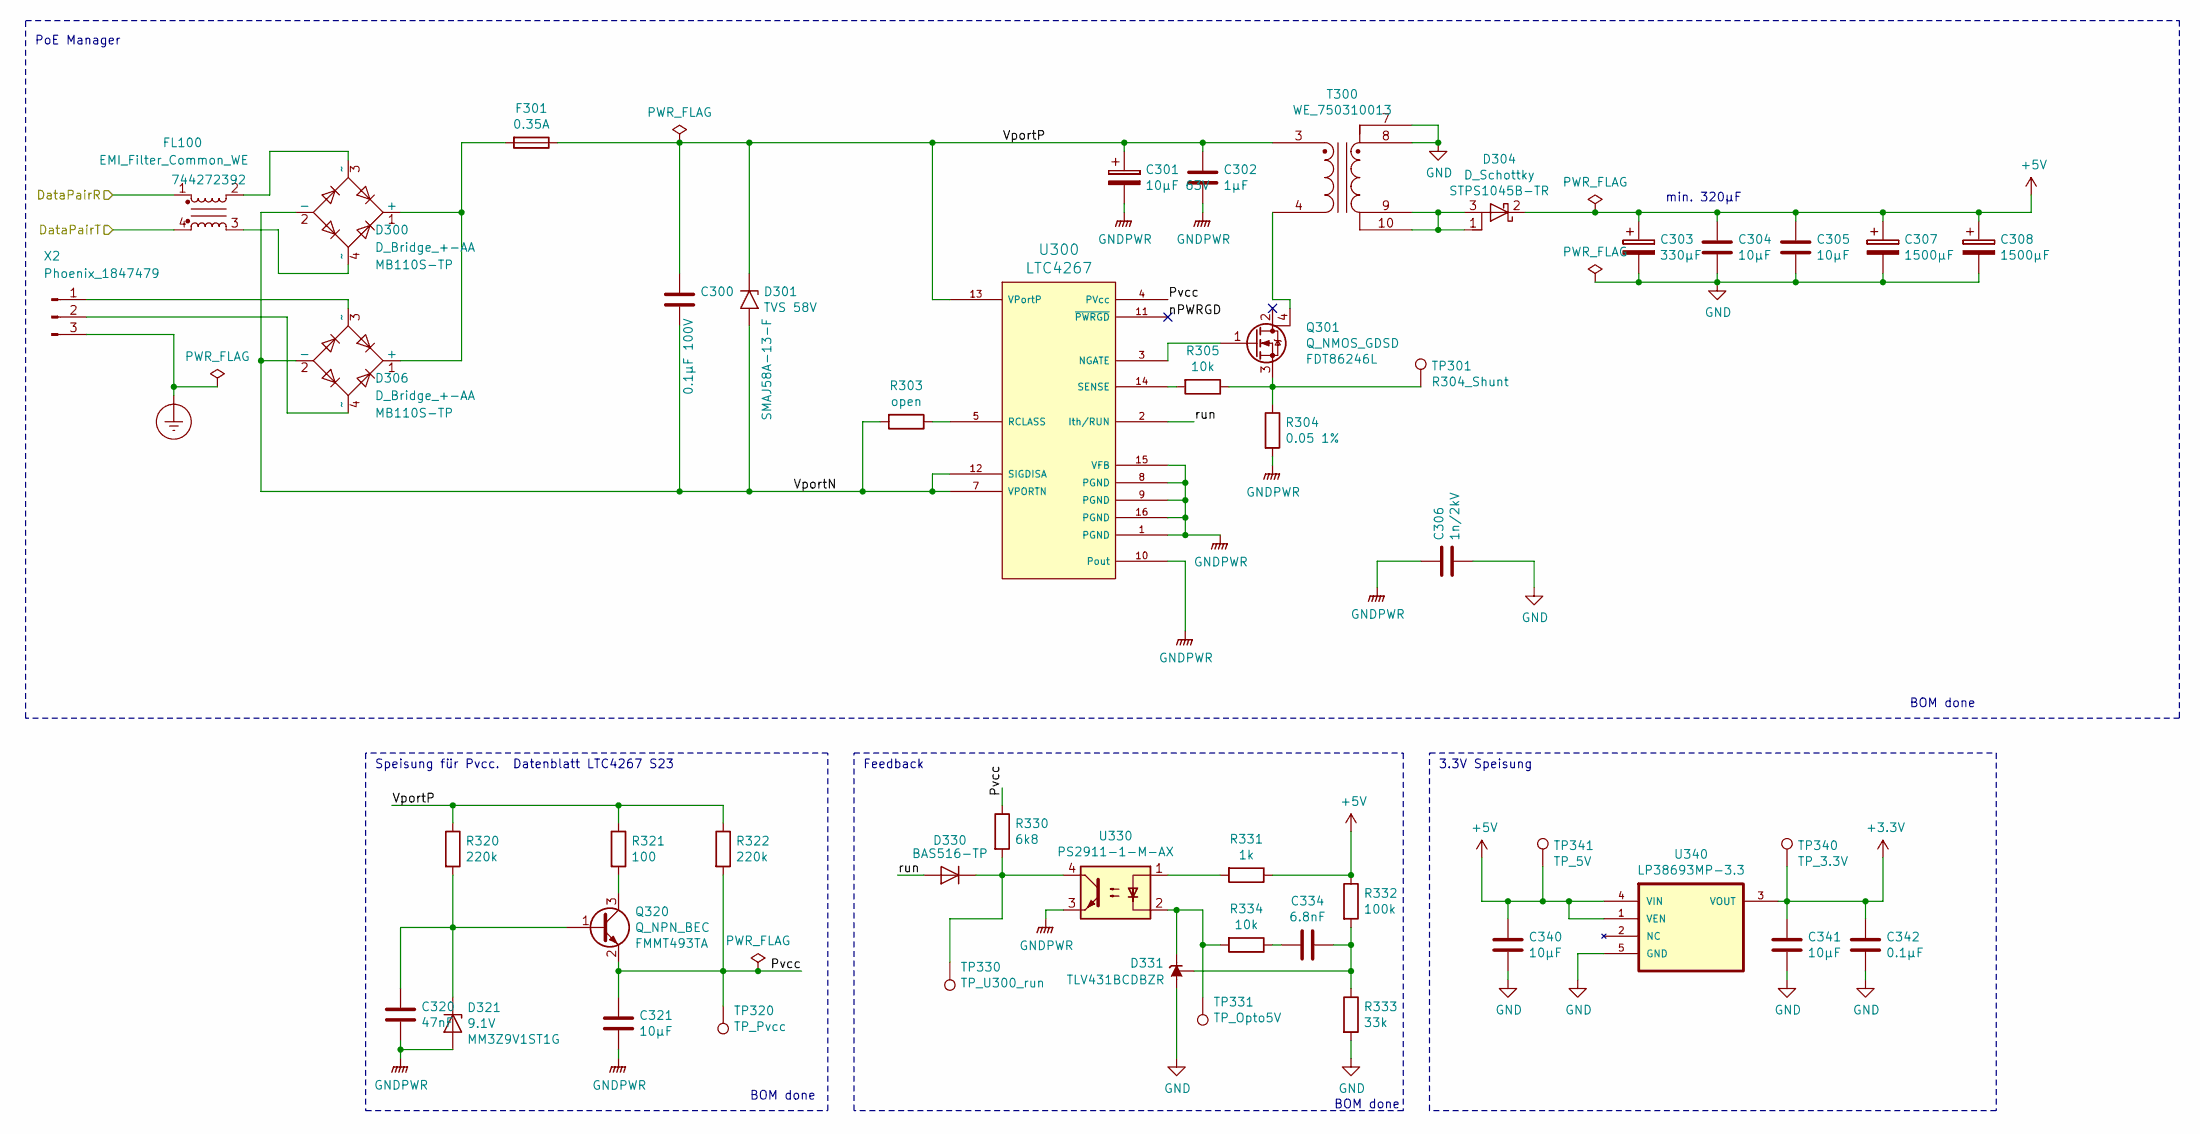
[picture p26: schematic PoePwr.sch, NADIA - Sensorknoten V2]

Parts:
C300: 0.1µF 100V; C_0805; part-num CGA4J2X7R2A104K125AA
C301: 10µF 63V; CP_Elec_6.3x5.8; part-num GYA1J100MCQ1GS
C302: 1µF; C_0805; part-num CGA4J3X7S2A105M125AE
C303: 330µF; CP_Elec_6.3x5.8; part-num 875105245015
C304, C305, C321, C340, C341: 10µF; C_0805; part-num CL21B106KOQNNNE
C306: 1n/2kV; C_Rect_L13.0mm_W4.0mm_P10.00mm_FKS3_FKP3_MKS4; part-num MKS4U011003C00KSSD
C307, C308: 1500µF; CP_Elec_10x10; part-num UCD0J152MNL1GS
C320: 47nF; C_0805; part-num 885012207070
C334: 6.8nF; C_0805; part-num 885012207121
C342: 0.1µF; C_0603; part-num CL10B104KO8NNNC
D300, D306: D_Bridge_+-AA; Diode_Bridge_TO-269AA; part-num MB110S-TP
D301: TVS 58V; D_SMA; part-num SMAJ58A-13-F
D304: D_Schottky; TO-252-3_TabPin2; part-num STPS1045B-TR
D321: 9.1V; D_SOD-323; part-num MM3Z9V1ST1G
D330: Fast Recovery; D_SOD-523; part-num BAS516-TP
D331: TLV431BCDBZR; SOT-23; part-num TLV431BCDBZR
F301: 0.35A; FuseHolder_Schurter_0031.7701.11; part-num 0031.7701.11;3404.0043.11
FL100: EMI_Filter_Common_WE; CommonModeChoke_WuerthType-WE-SL5; part-num 744272392
Q301: Q_NMOS_GDSD; SOT-223; part-num FDT86246L
Q320: Q_NPN_BEC; SOT-23; part-num FMMT493TA
R303: open; R_0805; part-num DNP
R304: 0.05 1%; R_1206; part-num CSNL1206FT50L0
R305, R334: 10k; R_0805; part-num ERJ-6ENF1002V
R320, R322: 220k; R_0805; part-num ERJ-6ENF2203V
R321: 100; R_0805; part-num ERJ-6ENF1000V
R330: 6k8; R_0805; part-num ERJ-6ENF6801V
R331: 1k; R_0805; part-num ERJ-6ENF1001V
R332: 100k; R_0805; part-num ERJ-6ENF1003V
R333: 33k; R_0805; part-num ERJ-6ENF3302V
T300: WE_750310013; WE_EP13; part-num 750310013
TP301: R304_Shunt; Measurement_Point_Round-SMD-Pad_Small; part-num DNP
TP320: TP_Pvcc; Measurement_Point_Round-SMD-Pad_Small; part-num DNP
TP330: TP_U300_run; Measurement_Point_Round-SMD-Pad_Small; part-num DNP
TP331: TP_Opto5V; Measurement_Point_Round-SMD-Pad_Small; part-num DNP
TP340: TP_3.3V; Measurement_Point_Round-SMD-Pad_Small; part-num DNP
TP341: TP_5V; Measurement_Point_Round-SMD-Pad_Small; part-num DNP
U300: LTC4267; SSOP-16_3.9x4.9mm_Pitch0.635mm; part-num LTC4267CGN#TRPBF
U330: PS2911; DIP-4_SMD_Opto; part-num PS2911-1-M-AX
U340: LP38693MP-3.3; SOT-223-5; part-num LP38693MP-3.3/NOPB
X2: Phoenix_1847479; PhoenixContact_MC-GF_03x5.08mm_Angled_ThreadedFlange; part-num 1847479

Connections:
+3V3: C341.1, C342.1, TP340.1, U340.3 (VOUT); also elsewhere on the board
+5V: C303.1, C304.1, C305.1, C307.1, C308.1, C340.1, D304.2 (K), R331.1, R332.1, TP341.1, U340.1 (VEN), U340.4 (VIN); also elsewhere on the board
/PoE und Speisung/DataPairR: FL100.1; also elsewhere on the board
/PoE und Speisung/DataPairT: FL100.4; also elsewhere on the board
/PoE und Speisung/Pvcc: C321.1, Q320.2 (E), R322.2, R330.1, TP320.1, U300.4 (PVcc)
/PoE und Speisung/VportN: C300.2, D300.2 (-), D301.2 (A2), D306.2 (-), R303.2, U300.7 (VPORTN), U300.12 (SIGDISA)
/PoE und Speisung/VportP: C300.1, C301.1, C302.1, D301.1 (A1), F301.1, R320.1, R321.1, R322.1, T300.3 (AA), U300.13 (VPortP)
/PoE und Speisung/nPWRGD: U300.11 (~PWRGD)
/PoE und Speisung/run: D330.2 (A), U300.2 (Ith/RUN)
Earth_Protective: X2.3; also elsewhere on the board
GND: C303.2, C304.2, C305.2, C306.2, C307.2, C308.2, C340.2, C341.2, C342.2, D331.3 (A), R333.2, T300.7, T300.8 (SB), U340.5 (GND); also elsewhere on the board
GNDPWR: C301.2, C302.2, C306.1, C320.2, C321.2, D321.2 (A), R304.2, U300.1 (PGND), U300.8 (PGND), U300.9 (PGND), U300.10 (Pout), U300.15 (VFB), U300.16 (PGND), U330.3
unnamed: C320.1, D321.1 (K), Q320.1 (B), R320.2
unnamed: C334.1, D331.1 (REF), R332.2, R333.1
unnamed: C334.2, R334.1
unnamed: D300.1 (+), D306.1 (+), F301.2
unnamed: D300.3 (~~), FL100.2
unnamed: D300.4 (~~), FL100.3
unnamed: D304.1 (A), D304.3 (A), T300.9 (SA), T300.10
unnamed: D306.3 (~~), X2.1
unnamed: D306.4 (~~), X2.2
unnamed: D330.1 (K), R330.2, TP330.1, U330.4
unnamed: D331.2 (K), R334.2, TP331.1, U330.2
unnamed: Q301.1 (G), U300.3 (NGATE)
unnamed: Q301.3 (S), R304.1, R305.1, TP301.1
unnamed: Q301.4 (D), T300.4 (AB)
unnamed: Q320.3 (C), R321.2
unnamed: R303.1, U300.5 (RCLASS)
unnamed: R305.2, U300.14 (SENSE)
unnamed: R331.2, U330.1

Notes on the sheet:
min. 320µF
Feedback
Speisung für Pvcc. Datenblatt LTC4267 S23
BOM done
PoE Manager
3.3V Speisung

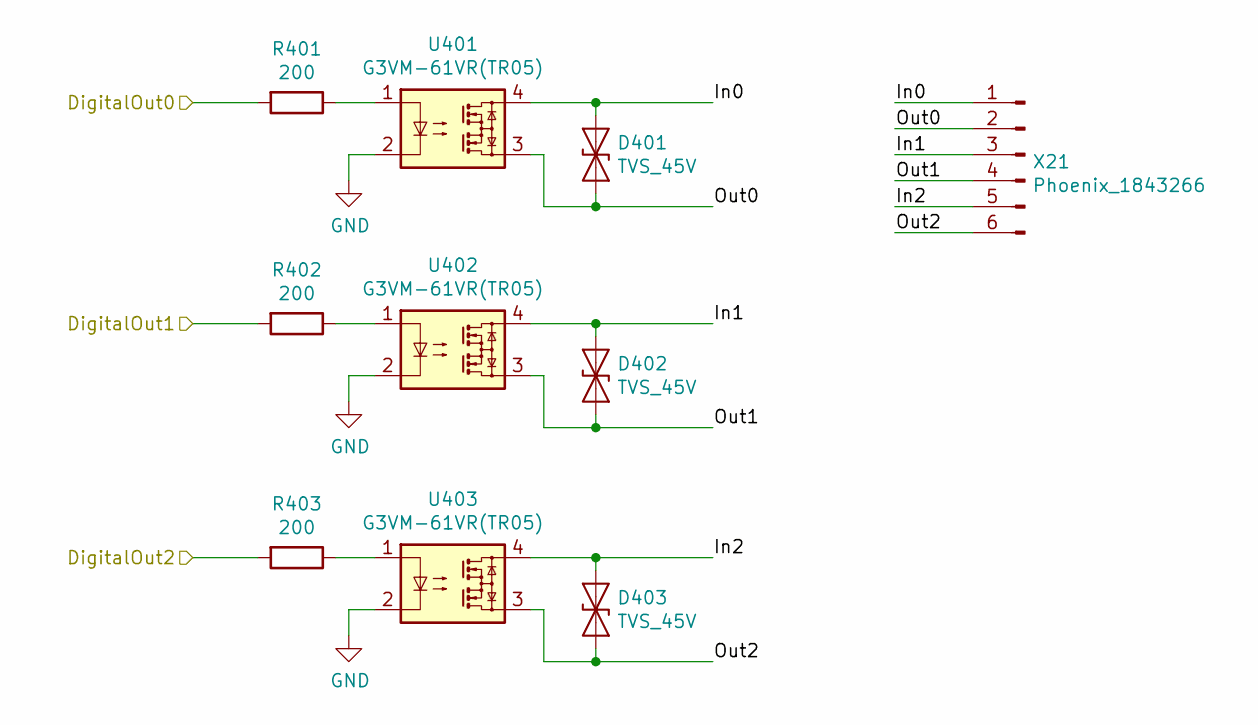
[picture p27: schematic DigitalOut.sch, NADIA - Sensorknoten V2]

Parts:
D401, D402, D403: TVS_45V; D_SMA; part-num SMAJ45CA-E3/61
R401, R402, R403: 200; R_0805; part-num ERJ-6ENF2000V
U401, U402, U403: G3VM-61VR(TR05); SOP-4_3.9x4.4mm_Pitch2.54mm; part-num G3VM-61VR(TR05)
X21: Phoenix_1843266; PhoenixContact_MCV-GF_06x3.50mm_Vertical_ThreadedFlange_Mou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; part-num 1843266

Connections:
/136_PWM0A: R401.2; also elsewhere on the board
/201_PWM1A: R403.2; also elsewhere on the board
/203_GPIO-0.23: R402.2; also elsewhere on the board
/Digitale Ausgänge/In0: D401.1 (A1), U401.4, X21.1
/Digitale Ausgänge/In1: D402.1 (A1), U402.4, X21.3
/Digitale Ausgänge/In2: D403.1 (A1), U403.4, X21.5
/Digitale Ausgänge/Out0: D401.2 (A2), U401.3, X21.2
/Digitale Ausgänge/Out1: D402.2 (A2), U402.3, X21.4
/Digitale Ausgänge/Out2: D403.2 (A2), U403.3, X21.6
GND: U401.2, U402.2, U403.2; also elsewhere on the board
unnamed: R401.1, U401.1
unnamed: R402.1, U402.1
unnamed: R403.1, U403.1

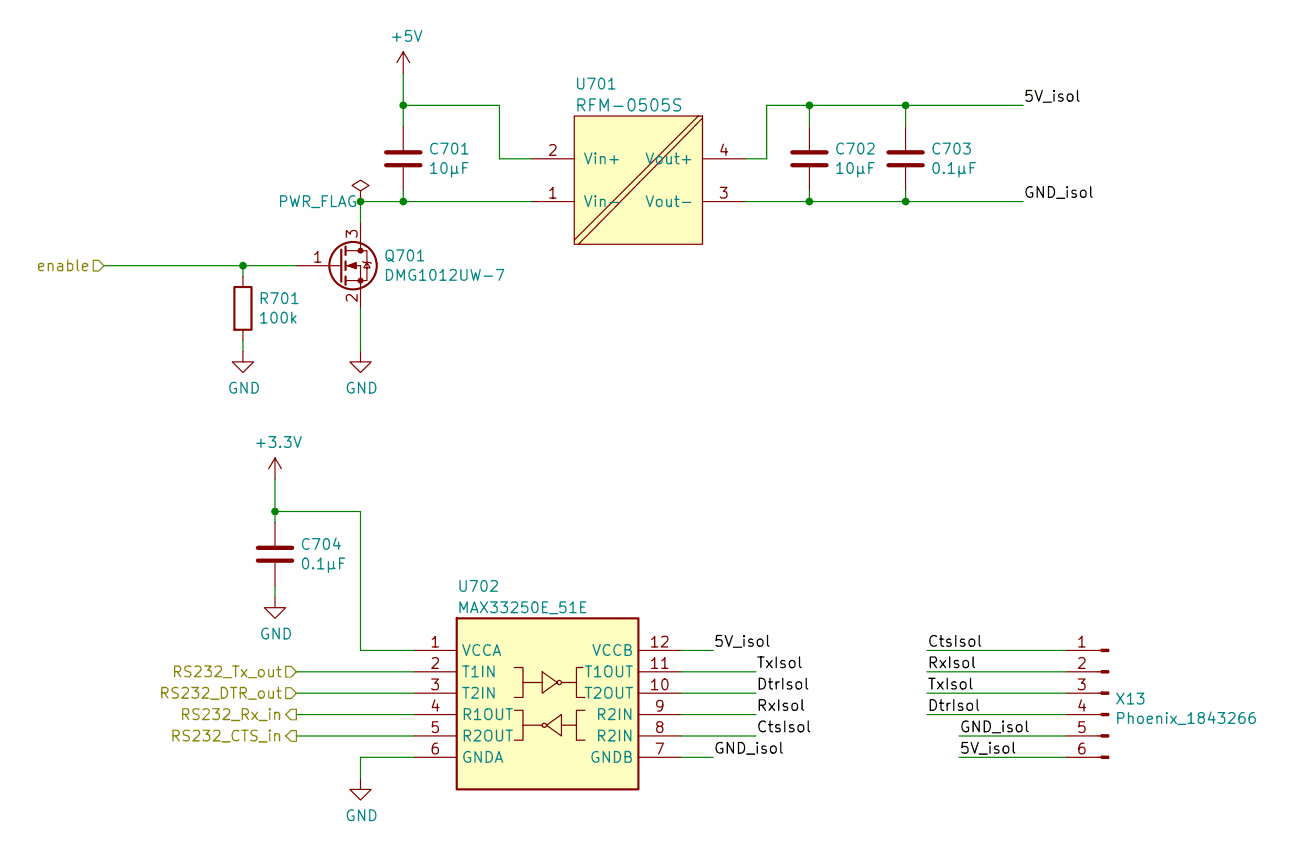
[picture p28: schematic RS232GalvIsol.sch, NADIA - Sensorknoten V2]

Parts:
C501, C502: 10µF; C_0805; part-num CL21B106KOQNNNE
C503, C504: 0.1µF; C_0603; part-num CL10B104KO8NNNC
Q501: DMG1012UW-7; SOT-323_SC-70; part-num DMG1012UW-7
R501: 100k; R_0805; part-num ERJ-6ENF1003V
U502: MAX33250E_51E; LGA-12; part-num MAX33250EELC+
U601: RFM-0505S; RFM-xxxxS; part-num RFM-0505S
X11: Phoenix_1843266; PhoenixContact_MCV-GF_06x3.50mm_Vertical_ThreadedFlange_Mou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; part-num 1843266

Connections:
+3V3: C504.1, U502.1 (VCCA); also elsewhere on the board
+5V: C501.1, U601.2 (Vin+); also elsewhere on the board
/106_SPI0.CS: U502.3 (T2IN); also elsewhere on the board
/112_SPI0.MOSI: U502.5 (R2OUT); also elsewhere on the board
/130_UART0.TX: U502.2 (T1IN); also elsewhere on the board
/132_UART0.RX: U502.4 (R1OUT); also elsewhere on the board
/134_GPIO-0.26: Q501.1 (G), R501.1; also elsewhere on the board
/RS232GalvIsol_0/CtsIsol: U502.8 (R2IN), X11.1
/RS232GalvIsol_0/DtrIsol: U502.10 (T2OUT), X11.4
/RS232GalvIsol_0/RxIsol: U502.9 (R2IN), X11.2
/RS232GalvIsol_0/TxIsol: U502.11 (T1OUT), X11.3
GND: C504.2, Q501.2 (S), R501.2, U502.6 (GNDA); also elsewhere on the board

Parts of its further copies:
C601, C602, C701, C702: 10µF; C_0805; part-num CL21B106KOQNNNE
C603, C604, C703, C704: 0.1µF; C_0603; part-num CL10B104KO8NNNC
Q601, Q701: DMG1012UW-7; SOT-323_SC-70; part-num DMG1012UW-7
R601, R701: 100k; R_0805; part-num ERJ-6ENF1003V
U501, U701: RFM-0505S; RFM-xxxxS; part-num RFM-0505S
U602, U702: MAX33250E_51E; LGA-12; part-num MAX33250EELC+
X12, X13: Phoenix_1843266; PhoenixContact_MCV-GF_06x3.50mm_Vertical_ThreadedFlange_Mou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; part-num 1843266

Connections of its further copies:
+3V3: C604.1, C704.1, U602.1 (VCCA), U702.1 (VCCA); also elsewhere on the board
+5V: C601.1, C701.1, U501.2 (Vin+), U701.2 (Vin+); also elsewhere on the board
/108_SPI0.CLK: U602.4 (R1OUT); also elsewhere on the board
/110_SPI0.MISO: U602.2 (T1IN); also elsewhere on the board
/131_PRU-0.4: U602.5 (R2OUT); also elsewhere on the board
/202_GPIO-1.27: U702.5 (R2OUT); also elsewhere on the board
/204_GPIO-1.26: Q701.1 (G), R701.1; also elsewhere on the board
/205_UART4.RX: U702.4 (R1OUT); also elsewhere on the board
/206_GPIO-1.25: U702.3 (T2IN); also elsewhere on the board
/207_UART4.TX: U702.2 (T1IN); also elsewhere on the board
/210_GPIO-1.20: Q601.1 (G), R601.1; also elsewhere on the board
/218_PRU-0.15: U602.3 (T2IN); also elsewhere on the board
/RS232GalvIsol_2/CtsIsol: U602.8 (R2IN), X12.1
/RS232GalvIsol_2/DtrIsol: U602.10 (T2OUT), X12.4
/RS232GalvIsol_2/RxIsol: U602.9 (R2IN), X12.2
/RS232GalvIsol_2/TxIsol: U602.11 (T1OUT), X12.3
/sheet5CAA8AE_4/5V_isol: C702.1, C703.1, U701.4 (Vout+), U702.12 (VCCB), X13.6
/sheet5CAA8AE_4/CtsIsol: U702.8 (R2IN), X13.1
/sheet5CAA8AE_4/DtrIsol: U702.10 (T2OUT), X13.4
/sheet5CAA8AE_4/GND_isol: C702.2, C703.2, U701.3 (Vout-), U702.7 (GNDB), X13.5
/sheet5CAA8AE_4/RxIsol: U702.9 (R2IN), X13.2
/sheet5CAA8AE_4/TxIsol: U702.11 (T1OUT), X13.3
GND: C604.2, C704.2, Q601.2 (S), Q701.2 (S), R601.2, R701.2, U602.6 (GNDA), U702.6 (GNDA); also elsewhere on the board
unnamed: C701.2, Q701.3 (D), U701.1 (Vin-)

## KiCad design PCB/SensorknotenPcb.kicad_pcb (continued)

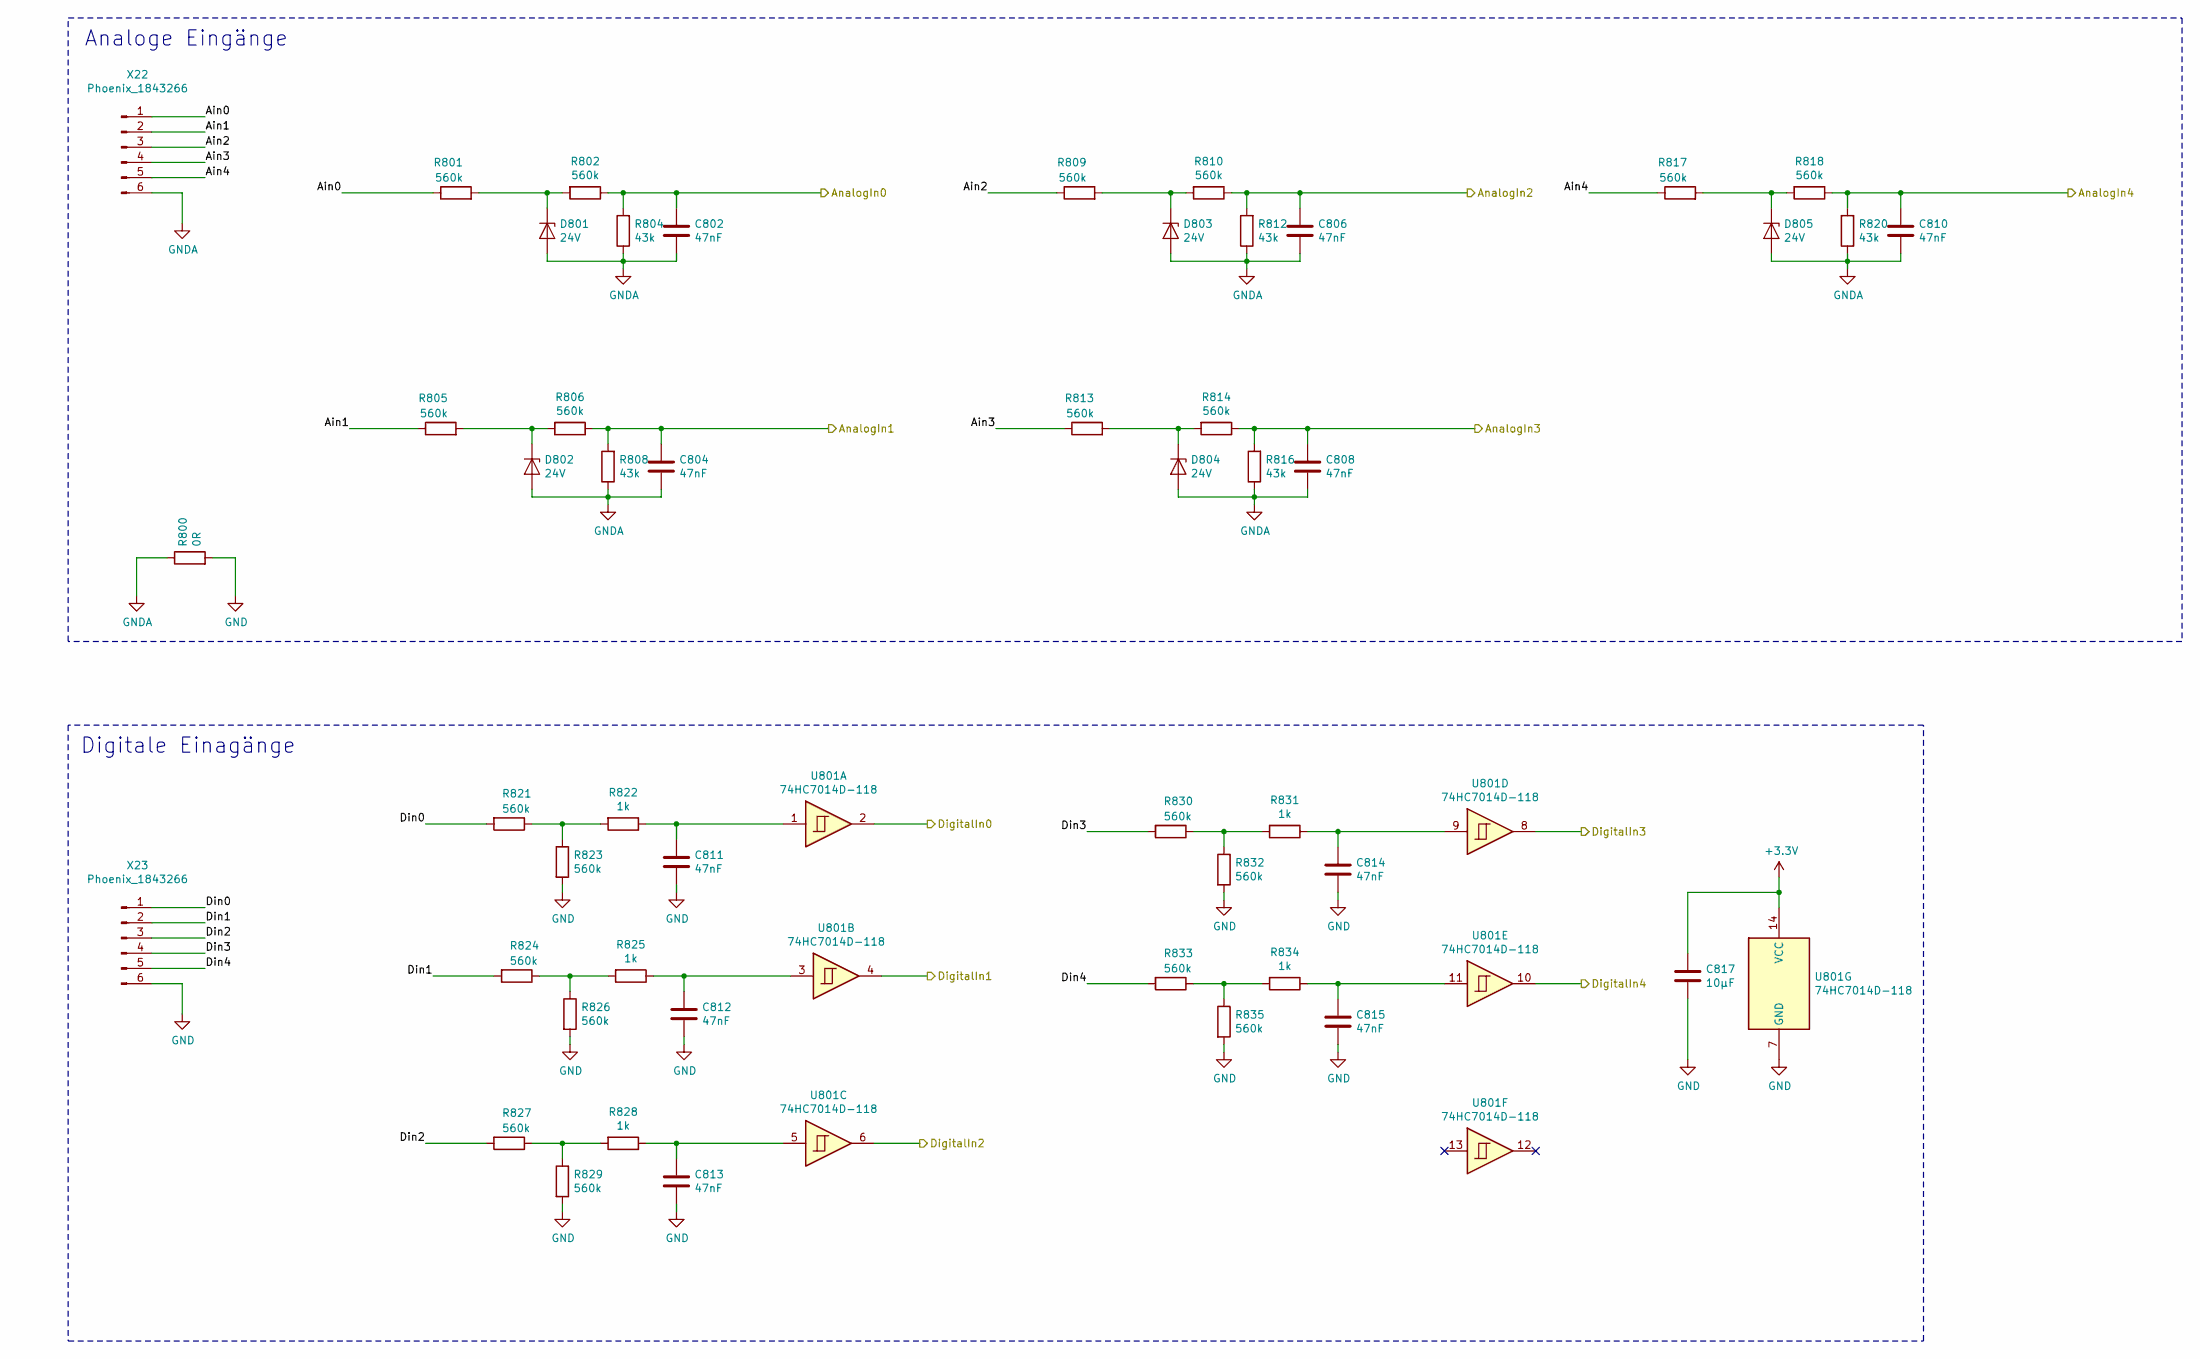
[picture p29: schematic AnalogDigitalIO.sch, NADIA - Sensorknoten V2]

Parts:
C802, C804, C806, C808, C810, C811, C812, C813, C814, C815: 47nF; C_0805; part-num 885012207070
C817: 10µF; C_0805; part-num CL21B106KOQNNNE
D801, D802, D803, D804, D805: 24V; D_SOD-323F; part-num BZX84J-B24-115
R800: 0R; R_0805; part-num ERJ-6GEY0R00V
R801, R802, R805, R806, R809, R810, R813, R814, R817, R818, R821, R823, R824, R826, R827, R829, R830, R832, R833, R835: 560k; R_0805; part-num RC0805JR-07560KL
R804, R808, R812, R816, R820: 43k; R_0805; part-num RC0805FR-0743KL
R822, R825, R828, R831, R834: 1k; R_0805; part-num ERJ-6ENF1001V
U801: 74HC7014D-118; SOIC-14_3.9x8.7mm_Pitch1.27mm; part-num 74HC7014D-118
X22, X23: Phoenix_1843266; PhoenixContact_MCV-GF_06x3.50mm_Vertical_ThreadedFlange_Mou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; part-num 1843266

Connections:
+3V3: C817.1, U801.14 (VCC); also elsewhere on the board
/119_AIN0_1.8V: C802.1, R802.1, R804.2; also elsewhere on the board
/121_AIN1_1.8V: C804.1, R806.1, R808.2; also elsewhere on the board
/123_AIN2_1.8V: C806.1, R810.1, R812.2; also elsewhere on the board
/125_AIN3_1.8V: C808.1, R814.1, R816.2; also elsewhere on the board
/127_AIN4_1.8V: C810.1, R818.1, R820.2; also elsewhere on the board
/133_PRU-0.1: U801.10; also elsewhere on the board
/228_PRU-0.6: U801.2; also elsewhere on the board
/230_PRU-0.3: U801.4; also elsewhere on the board
/232_PRU-0.2: U801.6; also elsewhere on the board
/234_PRU-0.5: U801.8; also elsewhere on the board
/Analoge und Digitale Eingänge/Ain0: R801.1, X22.1
/Analoge und Digitale Eingänge/Ain1: R805.1, X22.2
/Analoge und Digitale Eingänge/Ain2: R809.1, X22.3
/Analoge und Digitale Eingänge/Ain3: R813.1, X22.4
/Analoge und Digitale Eingänge/Ain4: R817.1, X22.5
/Analoge und Digitale Eingänge/Din0: R821.2, X23.1
/Analoge und Digitale Eingänge/Din1: R824.2, X23.2
/Analoge und Digitale Eingänge/Din2: R827.2, X23.3
/Analoge und Digitale Eingänge/Din3: R830.2, X23.4
/Analoge und Digitale Eingänge/Din4: R833.2, X23.5
GND: C811.2, C812.2, C813.2, C814.2, C815.2, C817.2, R800.2, R823.2, R826.2, R829.2, R832.2, R835.2, U801.7 (GND), X23.6; also elsewhere on the board
GNDA: C802.2, C804.2, C806.2, C808.2, C810.2, D801.2 (A), D802.2 (A), D803.2 (A), D804.2 (A), D805.2 (A), R800.1, R804.1, R808.1, R812.1, R816.1, R820.1, X22.6; also elsewhere on the board
unnamed: C811.1, R822.1, U801.1
unnamed: C812.1, R825.1, U801.3
unnamed: C813.1, R828.1, U801.5
unnamed: C814.1, R831.1, U801.9
unnamed: C815.1, R834.1, U801.11
unnamed: D801.1 (K), R801.2, R802.2
unnamed: D802.1 (K), R805.2, R806.2
unnamed: D803.1 (K), R809.2, R810.2
unnamed: D804.1 (K), R813.2, R814.2
unnamed: D805.1 (K), R817.2, R818.2
unnamed: R821.1, R822.2, R823.1
unnamed: R824.1, R825.2, R826.1
unnamed: R827.1, R828.2, R829.1
unnamed: R830.1, R831.2, R832.1
unnamed: R833.1, R834.2, R835.1

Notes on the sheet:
Analoge Eingänge
Digitale Einagänge

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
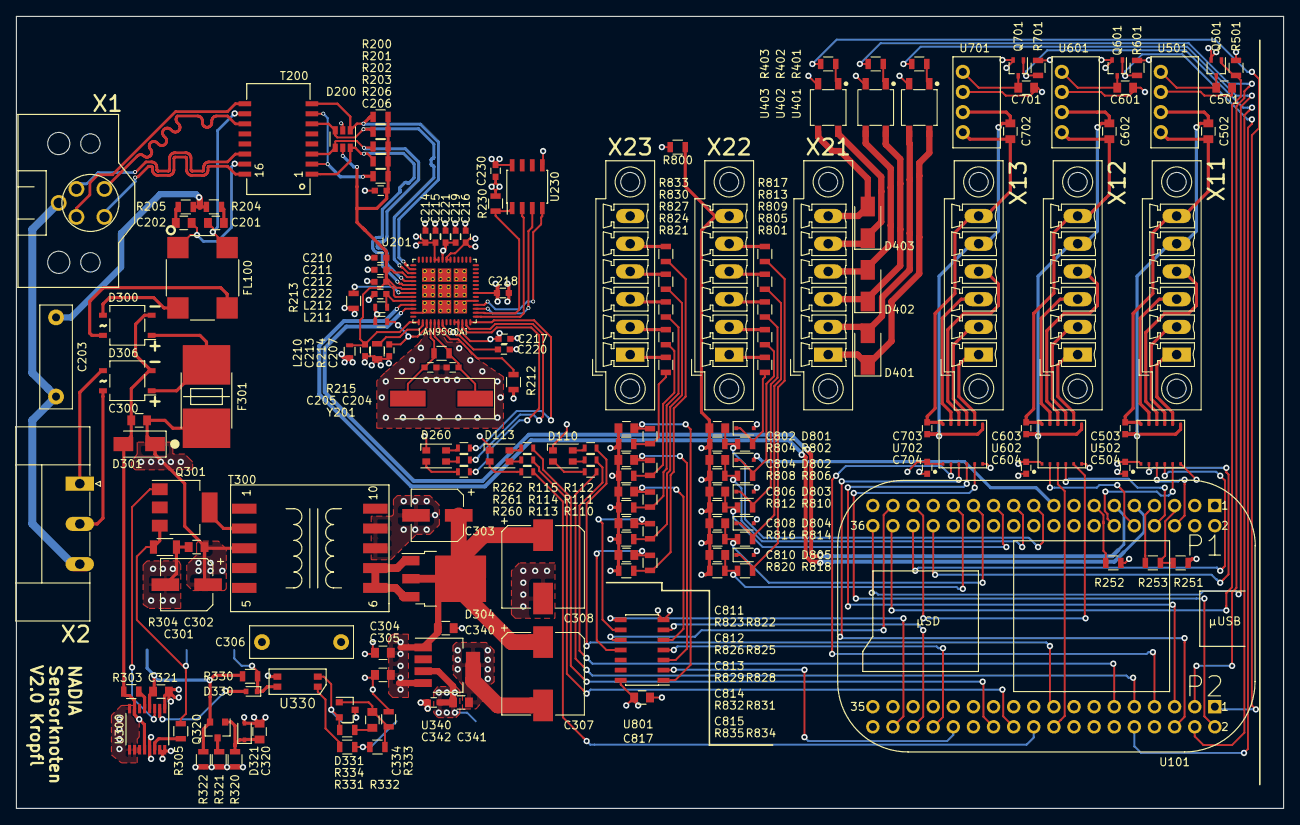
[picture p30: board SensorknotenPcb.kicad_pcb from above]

Board: 4 copper layers, 160.0 x 100.0 mm, 193 parts (0 on the bottom side), 161 nets.

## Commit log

2022-10-30 Initialer Upload
    [AnalogDigitalIO.sch, BBB_Pins.xlsx, CAN.sch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]
2024-04-24 Update README.md
    Bilder vom PCB und Gehäuse in eine Tabelle verschoben
